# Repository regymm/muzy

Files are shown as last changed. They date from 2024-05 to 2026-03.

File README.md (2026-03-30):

# MUZY

AMD/Xilinx ZYNQ 7010/7020 SoC as generic FPGA development board, no DDR -- cheaper than your Artix 7! 

## MUZY-2

[BGA on 2-layers? It's possible and verified!](muzy2.md)

## MUZY-4

[Now on sale!]()

**Hardware**

- Zynq 7020 (xc7z020-clg400-1)

- RP2040-based JTAG blaster, with DirtyJTAG / XVC Pico firmware, working with OpenFPGALoader and Vivado

- Dual SD Card PS + PL

- Dual Video Out HDMI + VGA 

- Dual USB Host

- Dual PMOD

- 2 switches, 2 buttons, 4 LEDs

- 256 Mb (32 MB) SDRAM

Should be perfect for SoC development & work as a handhold FPGA computer! 

Open-source [Zynq](https://github.com/regymm/GenZ)/[FPGA](https://github.com/OpenXC7) toolchains recommended! 

**JTAG**

There're 3 ways to program the FPGA by JTAG: 

1. Use the standard 2x5 pin header with an external Xilinx dongle.
2. Use the on-board pluggable RP2040 module and [the dirtyJtag firwmare](https://github.com/regymm/pico-dirtyJtag), `./pico_fw/dirtyJtag.uf2`. This supports `openFPGALoader -c dirtyJtag bitstream.bit` style direct programming. Simultaneous UART access also available, usually `/dev/ttyACM0`. Vivado access (and thus ILA) not supported by this firmware. 
3. Use the on-board pluggable RP2040 module and [the xvcPico firmware](https://github.com/regymm/xvc-pico), `./pico_fw/xvcPico.uf2`. Then, launch the daemon in xvcPico (`xvcd-pico`) and 127.0.0.1:2542 for XVC access in Vivado. openFPGALoader can still be used with `openFPGALoader -c xvc-client  --ip 127.1 --port 2542 bitstrea.bit`. Simultaneous UART access also available, usually `/dev/ttyACM0`. 

- For RP Pico firmware update, press the BOOT button down while connecting the USB-C cable, a USB-like device will show up on PC for firmware uploading. 

**Software**

Tested: [Zynq PS No-DDR SD Boot](https://github.com/regymm/GenZ/tree/master/examples/6-noddr-sdboot), [RISC-V SoC Linux booting from SD Card](https://github.com/regymm/quasiSoC/tree/master/rtl/hart_transplant/openla500), Dual video output

**Gallery**

Video: [Linux UART with dual graphics test output](https://www.youtube.com/shorts/H9cZ7YbqNOI)

Pictures: 

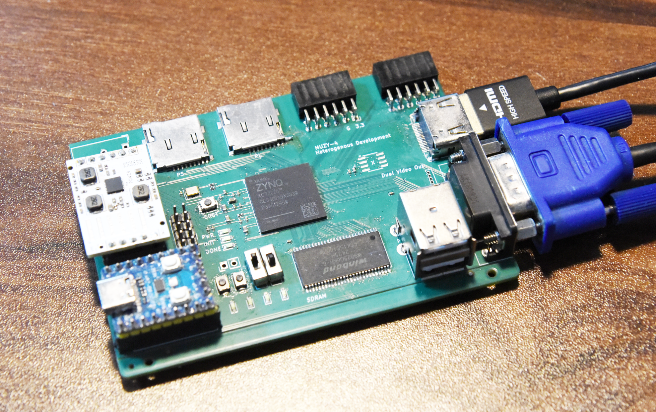
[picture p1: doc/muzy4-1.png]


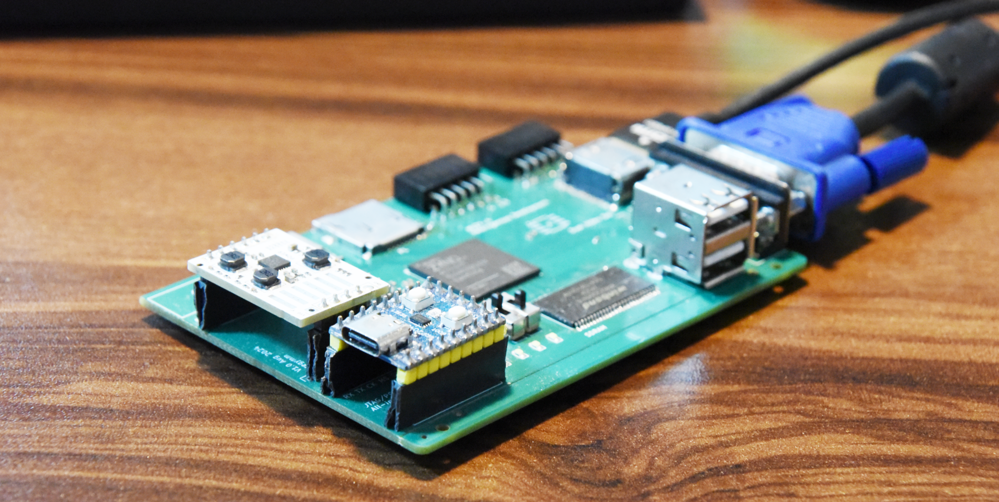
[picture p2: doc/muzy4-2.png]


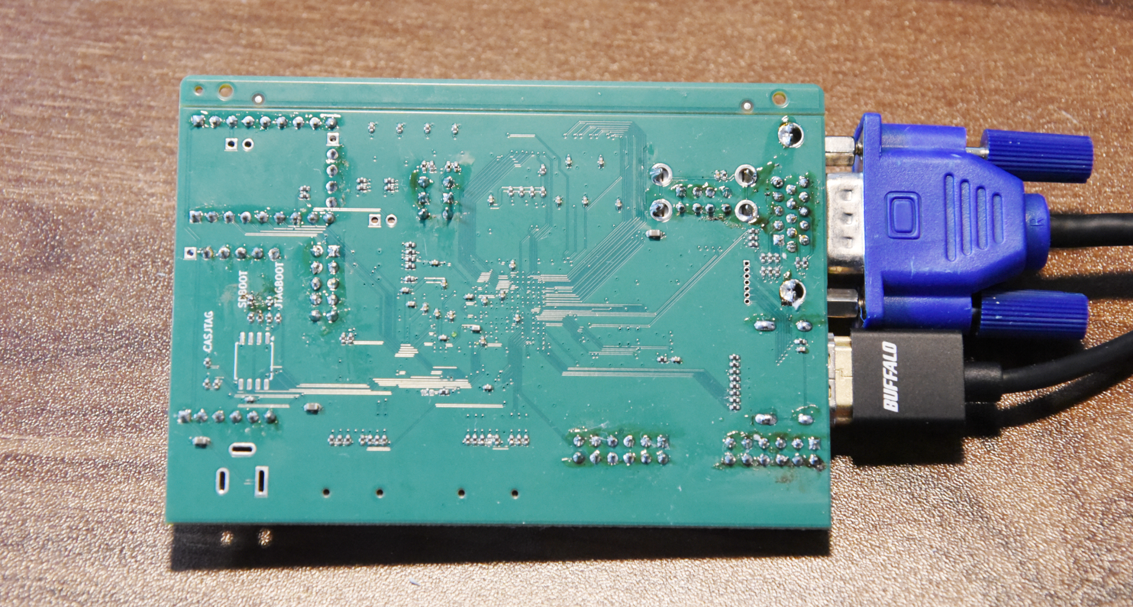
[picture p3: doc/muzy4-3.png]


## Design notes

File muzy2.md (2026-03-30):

# Muzy-2
2-layer FPGA development board with ZYNQ 7010/7020 400-pin BGA.  
Pad size was shrinked due to clearance requirements -- JLCPCB 2-layer 5 mil line width, 0.5/0.3 mm via. 

## Working

PL(FPGA fabric) JTAG & bitstream downloading, SDRAM tested up to 110 MHz, 640x480 VGA, BTN/LED, PMOD

Loading PS(ARM cores) program via JTAG in Xilinx SDK, PS UART, PS SD card, PS EMIO

## Not Working

PL SD card -- due to no pullup resistors! A PMOD SD card module works.

~~PS load bitstream from SD card -- it seems impossible due to no big enough block of memory. Either SPI flash or DDR is required.~~ Now working with GenZ. 

JTAG at 30 MHz maybe not stable. 

## Gallery

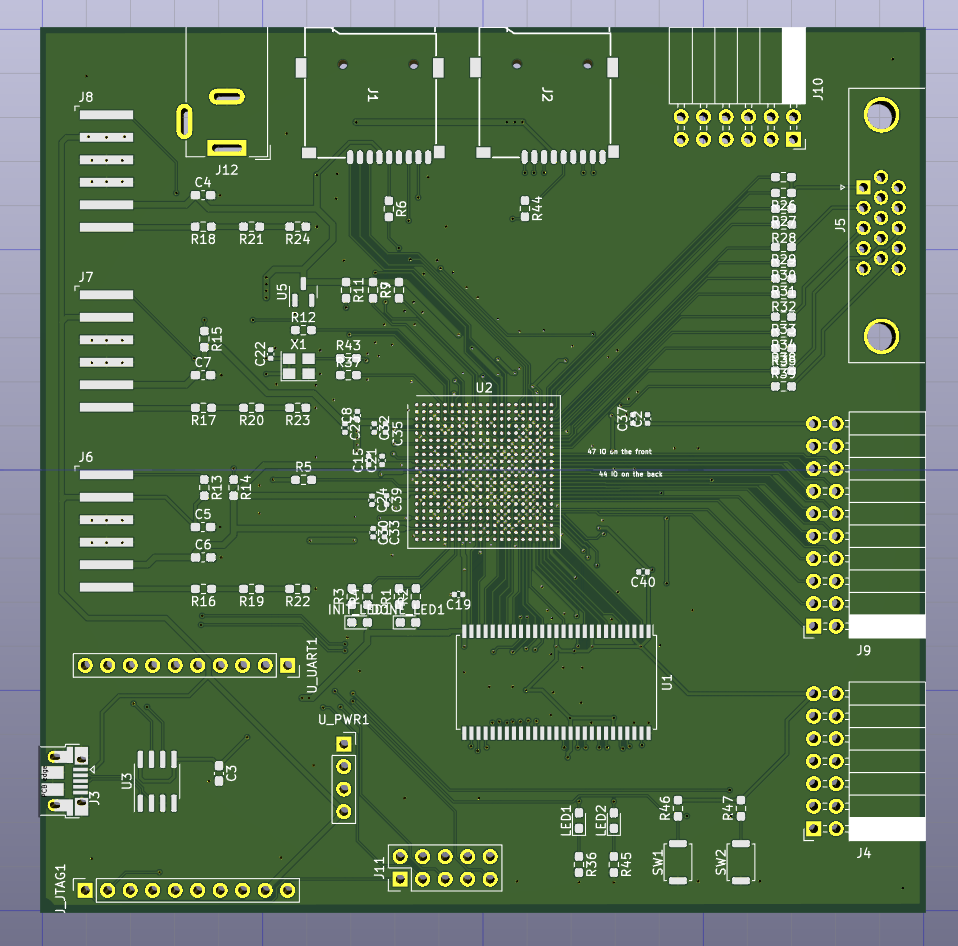
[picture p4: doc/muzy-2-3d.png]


Running with [self-designed JTAG/UART bridge](https://github.com/regymm/ymmcu-ft2232)

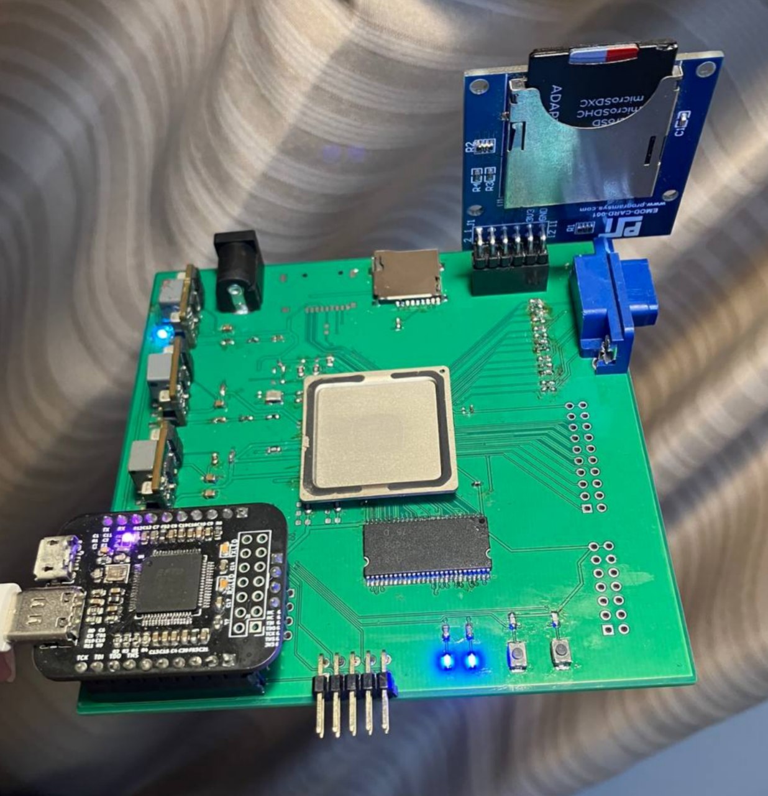
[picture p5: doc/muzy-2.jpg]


Minimum configuration with external power supply and just a few resistors -- back side empty! 



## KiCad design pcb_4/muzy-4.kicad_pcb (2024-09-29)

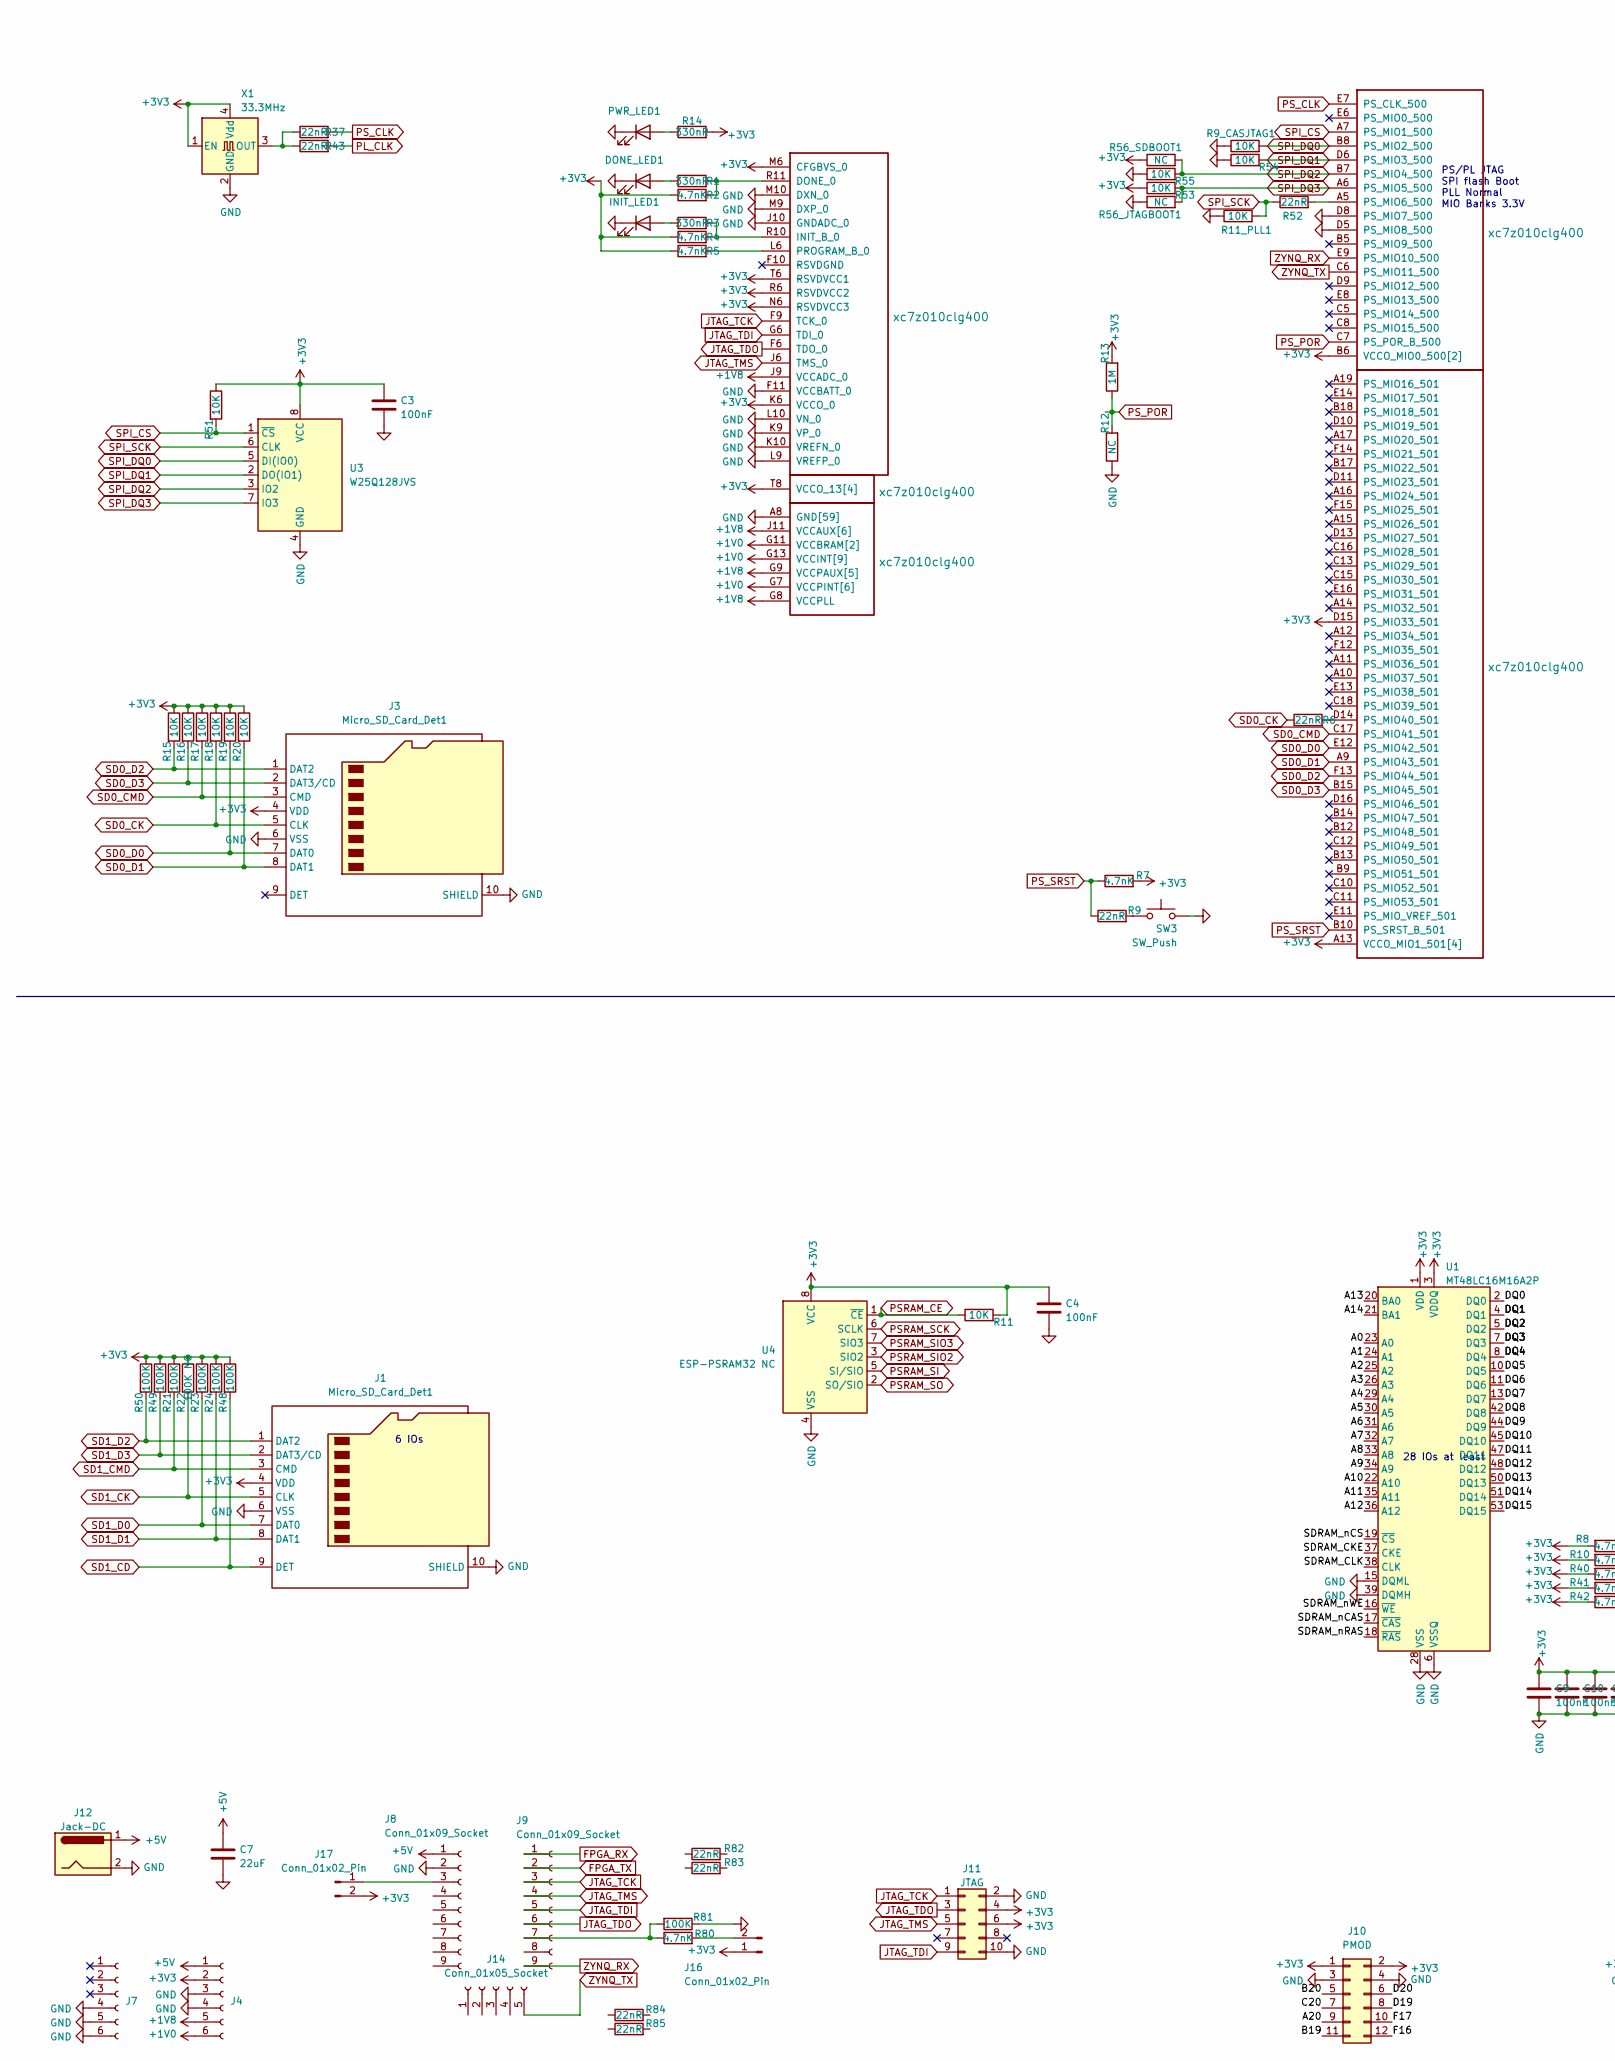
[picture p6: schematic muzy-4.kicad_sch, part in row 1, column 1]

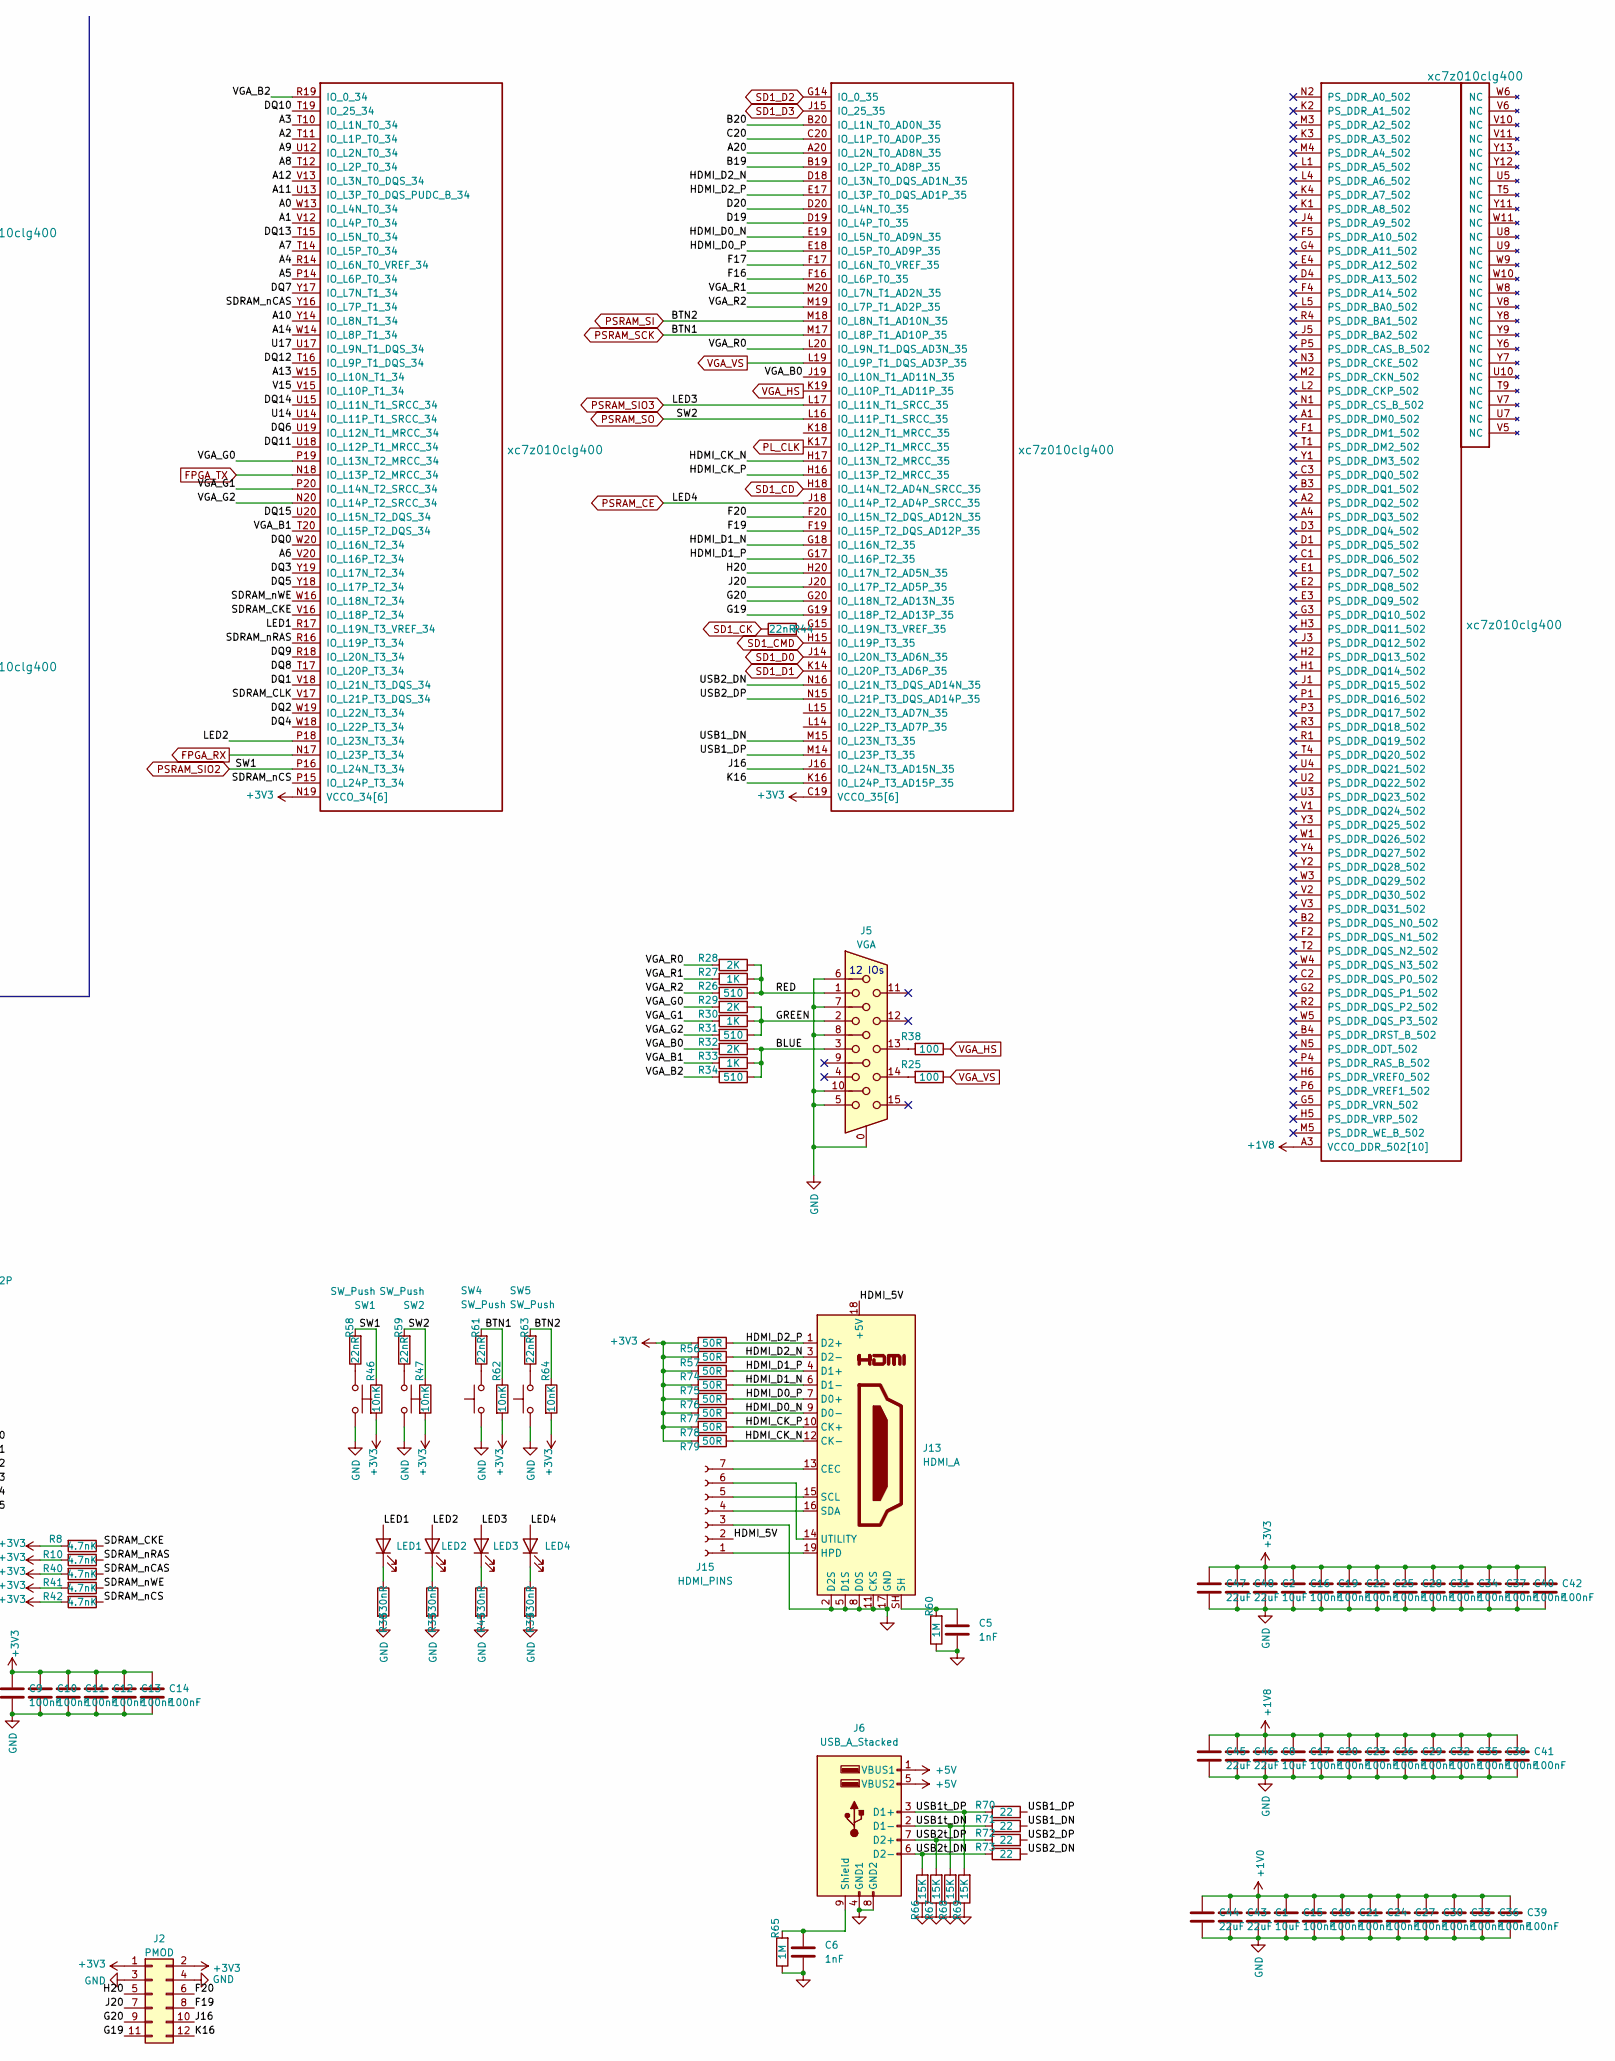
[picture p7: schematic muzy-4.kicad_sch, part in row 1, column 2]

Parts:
C1, C2, C8: 10uF; C_0402_1005Metric
C3, C4, C9, C10, C11, C12, C13, C14, C15, C16, C17, C18, C19, C20, C21, C22, C23, C24, C25, C26, C27, C28, C29, C30, C31, C32, C33, C34, C35, C36, C37, C38, C39, C40, C41, C42: 100nF; C_0402_1005Metric
C5, C6: 1nF; C_0402_1005Metric
C7, C43, C44, C45, C46, C47, C48: 22uF; C_0603_1608Metric
DONE_LED1: LED; LED_0603_1608Metric_Pad1.05x0.95mm_HandSolder
INIT_LED1: LED; LED_0603_1608Metric_Pad1.05x0.95mm_HandSolder
J1, J3: Micro_SD_Card_Det1; SDMICRO_AT
J2, J10: PMOD; PinSocket_2x06_P2.54mm_Horizontal
J4, J7: Conn_01x06_Socket; PinSocket_1x06_P2.54mm_Vertical
J5: VGA; DSUB-15-HD_Female_Horizontal_P2.29x1.98mm_EdgePinOffset3.03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
J6: USB_A_Stacked; USB_A_CUI_UJ2-ADH-TH_Horizontal_Stacked
J8, J9: Conn_01x09_Socket; PinSocket_1x09_P2.54mm_Vertical
J11: JTAG; PinHeader_2x05_P2.54mm_Vertical
J12: Jack-DC; BarrelJack_Wuerth_6941xx301002
J13: HDMI_A; HDMI_A_Molex_208658-1001_Horizontal
J14: Conn_01x05_Socket; PinSocket_1x05_P2.54mm_Vertical
J15: HDMI_PINS; PinSocket_1x07_P1.00mm_Vertical
J16, J17: Conn_01x02_Pin; PinHeader_1x02_P2.54mm_Vertical
LED1, LED2, LED3, LED4: LED; LED_0603_1608Metric_Pad1.05x0.95mm_HandSolder
PWR_LED1: LED; LED_0603_1608Metric_Pad1.05x0.95mm_HandSolder
R1, R3, R14, R35, R36, R39, R45: 330nR; R_0402_1005Metric
R2, R4, R5, R7, R8, R10, R40, R41, R42, R80: 4.7nK; R_0402_1005Metric
R6, R9, R37, R43, R44, R52, R58, R59, R61, R63, R82, R83, R84, R85: 22nR; R_0402_1005Metric
R9_CASJTAG1, R11, R11_PLL1, R15, R16, R17, R18, R19, R20, R51, R53, R54, R55: 10K; R_0402_1005Metric
R12: NC; R_0402_1005Metric_Pad0.72x0.64mm_HandSolder
R13, R65: 1M; R_0402_1005Metric
R21, R23, R24, R48, R49, R50, R81: 100K; R_0402_1005Metric
R22: 100K NC; R_0402_1005Metric
R25, R38: 100; R_0402_1005Metric
R26, R31, R34: 510; R_0402_1005Metric
R27, R30, R33: 1K; R_0402_1005Metric
R28, R29, R32: 2K; R_0402_1005Metric
R46, R47, R62, R64: 10nK; R_0402_1005Metric
R56, R57, R74, R75, R76, R77, R78, R79: 50R; R_0402_1005Metric
R56_JTAGBOOT1, R56_SDBOOT1: NC; R_0402_1005Metric
R60: 1M; R_0402_1005Metric_Pad0.72x0.64mm_HandSolder
R66, R67, R68, R69: 15K; R_0402_1005Metric
R70, R71, R72, R73: 22; R_0402_1005Metric
SW1, SW2: SW_Push; SW_Slide-03_Wuerth-WS-SLTV_10x2.5x6.4_P2.54mm
SW3, SW4, SW5: SW_Push; SW_Push_SPST_NO_Alps_SKRK
U1: MT48LC16M16A2P; TSOP-II-54_22.2x10.16mm_P0.8mm
U2: xc7z010clg400; Xilinx_CLG400_NoPaste_JLC_Package_Delay
U3: W25Q128JVS; SOIC-8_5.23x5.23mm_P1.27mm
U4: ESP-PSRAM32 NC; SOIC-8_3.9x4.9mm_P1.27mm
X1: 33.3MHz; Crystal_SMD_3225-4Pin_3.2x2.5mm

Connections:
+1V0: C1.1, C15.1, C18.1, C21.1, C24.1, C27.1, C30.1, C33.1, C36.1, C39.1, C43.1, C44.1, J4.6, U2.G7 (VCCPINT[6]), U2.G11 (VCCBRAM[2]), U2.G13 (VCCINT[9]), U2.H10 (VCCBRAM[2]), U2.H12 (VCCINT[9]), U2.J7 (VCCPINT[6]), U2.J13 (VCCINT[9]), U2.K12 (VCCINT[9]), U2.L7 (VCCPINT[6]), U2.L13 (VCCINT[9]), U2.M12 (VCCINT[9]), U2.N7 (VCCPINT[6]), U2.N13 (VCCINT[9]), U2.P8 (VCCPINT[6]), U2.P12 (VCCINT[9]), U2.R7 (VCCPINT[6]), U2.R13 (VCCINT[9])
+1V8: C8.1, C17.1, C20.1, C23.1, C26.1, C29.1, C32.1, C35.1, C38.1, C41.1, C45.1, C46.1, J4.5, U2.A3 (VCCO_DDR_502[10]), U2.D2 (VCCO_DDR_502[10]), U2.E5 (VCCO_DDR_502[10]), U2.F8 (VCCPAUX[5]), U2.G1 (VCCO_DDR_502[10]), U2.G8 (VCCPLL), U2.G9 (VCCPAUX[5]), U2.H4 (VCCO_DDR_502[10]), U2.H8 (VCCPAUX[5]), U2.J9 (VCCADC_0), U2.J11 (VCCAUX[6]), U2.K8 (VCCPAUX[5]), U2.L3 (VCCO_DDR_502[10]), U2.L11 (VCCAUX[6]), U2.M8 (VCCPAUX[5]), U2.N9 (VCCAUX[6]), U2.N11 (VCCAUX[6]), U2.P2 (VCCO_DDR_502[10]), U2.P10 (VCCAUX[6]), U2.R5 (VCCO_DDR_502[10]), U2.R9 (VCCAUX[6]), U2.U1 (VCCO_DDR_502[10]), U2.V4 (VCCO_DDR_502[10])
+3V3: C2.1, C3.1, C4.1, C9.1, C10.1, C11.1, C12.1, C13.1, C14.1, C16.1, C19.1, C22.1, C25.1, C28.1, C31.1, C34.1, C37.1, C40.1, C42.1, C47.1, C48.1, J1.4 (VDD), J2.1, J2.2, J3.4 (VDD), J4.2, J10.1, J10.2, J11.4, J11.6, J16.1, J17.2, R2.1, R4.1, R5.1, R7.2, R8.2, R10.2, R11.2, R13.2, R14.2, R15.1, R16.1, R17.1, R18.1, R19.1, R20.1, R21.1, R22.1, R23.1, R24.1, R40.2, R41.2, R42.2, R46.2, R47.2, R48.1, R49.1, R50.1, R51.1, R53.1, R56.2, R56_SDBOOT1.1, R57.2, R62.2, R64.2, R74.2, R75.2, R76.2, R77.2, R78.2, R79.2, U1.1 (VDD), U1.3 (VDDQ), U1.9 (VDDQ), U1.14 (VDD), U1.27 (VDD), U1.43 (VDDQ), U1.49 (VDDQ), U2.A13 (VCCO_MIO1_501[4]), U2.B6 (VCCO_MIO0_500[2]), U2.B16 (VCCO_MIO1_501[4]), U2.C19 (VCCO_35[6]), U2.D7 (VCCO_MIO0_500[2]), U2.D12 (VCCO_MIO1_501[4]), U2.D15 (PS_MIO33_501), U2.E15 (VCCO_MIO1_501[4]), U2.F18 (VCCO_35[6]), U2.H14 (VCCO_35[6]), U2.J17 (VCCO_35[6]), U2.K6 (VCCO_0), U2.K20 (VCCO_35[6]), U2.M6 (CFGBVS_0), U2.M16 (VCCO_35[6]), U2.N6 (RSVDVCC3), U2.N19 (VCCO_34[6]), U2.R6 (RSVDVCC2), U2.R15 (VCCO_34[6]), U2.T6 (RSVDVCC1), U2.T8 (VCCO_13[4]), U2.T18 (VCCO_34[6]), U2.U11 (VCCO_13[4]), U2.V14 (VCCO_34[6]), U2.W7 (VCCO_13[4]), U2.W17 (VCCO_34[6]), U2.Y10 (VCCO_13[4]), U2.Y20 (VCCO_34[6]), U3.8 (VCC), U4.8 (VCC), X1.1 (EN), X1.4 (Vdd)
+5V: C7.1, J4.1, J6.1 (VBUS1), J6.5 (VBUS2), J8.1, J12.1
/A0: U1.23 (A0), U2.W13 (IO_L4N_T0_34)
/A1: U1.24 (A1), U2.V12 (IO_L4P_T0_34)
/A2: U1.25 (A2), U2.T11 (IO_L1P_T0_34)
/A3: U1.26 (A3), U2.T10 (IO_L1N_T0_34)
/A4: U1.29 (A4), U2.R14 (IO_L6N_T0_VREF_34)
/A5: U1.30 (A5), U2.P14 (IO_L6P_T0_34)
/A6: U1.31 (A6), U2.V20 (IO_L16P_T2_34)
/A7: U1.32 (A7), U2.T14 (IO_L5P_T0_34)
/A8: U1.33 (A8), U2.T12 (IO_L2P_T0_34)
/A9: U1.34 (A9), U2.U12 (IO_L2N_T0_34)
/A10: U1.22 (A10), U2.Y14 (IO_L8N_T1_34)
/A11: U1.35 (A11), U2.U13 (IO_L3P_T0_DQS_PUDC_B_34)
/A12: U1.36 (A12), U2.V13 (IO_L3N_T0_DQS_34)
/A13: U1.20 (BA0), U2.W15 (IO_L10N_T1_34)
/A14: U1.21 (BA1), U2.W14 (IO_L8P_T1_34)
/A20: J10.9, U2.A20 (IO_L2N_T0_AD8N_35)
/B19: J10.11, U2.B19 (IO_L2P_T0_AD8P_35)
/B20: J10.5, U2.B20 (IO_L1N_T0_AD0N_35)
/BLUE: J5.3, R32.1, R33.1, R34.1
/C20: J10.7, U2.C20 (IO_L1P_T0_AD0P_35)
/D19: J10.8, U2.D19 (IO_L4P_T0_35)
/D20: J10.6, U2.D20 (IO_L4N_T0_35)
/DQ0: U1.2 (DQ0), U2.W20 (IO_L16N_T2_34)
/DQ1: U1.4 (DQ1), U2.V18 (IO_L21N_T3_DQS_34)
/DQ2: U1.5 (DQ2), U2.W19 (IO_L22N_T3_34)
/DQ3: U1.7 (DQ3), U2.Y19 (IO_L17N_T2_34)
/DQ4: U1.8 (DQ4), U2.W18 (IO_L22P_T3_34)
/DQ5: U1.10 (DQ5), U2.Y18 (IO_L17P_T2_34)
/DQ6: U1.11 (DQ6), U2.U19 (IO_L12N_T1_MRCC_34)
/DQ7: U1.13 (DQ7), U2.Y17 (IO_L7N_T1_34)
/DQ8: U1.42 (DQ8), U2.T17 (IO_L20P_T3_34)
/DQ9: U1.44 (DQ9), U2.R18 (IO_L20N_T3_34)
/DQ10: U1.45 (DQ10), U2.T19 (IO_25_34)
/DQ11: U1.47 (DQ11), U2.U18 (IO_L12P_T1_MRCC_34)
/DQ12: U1.48 (DQ12), U2.T16 (IO_L9P_T1_DQS_34)
/DQ13: U1.50 (DQ13), U2.T15 (IO_L5N_T0_34)
/DQ14: U1.51 (DQ14), U2.U15 (IO_L11N_T1_SRCC_34)
/DQ15: U1.53 (DQ15), U2.U20 (IO_L15N_T2_DQS_34)
/F16: J10.12, U2.F16 (IO_L6P_T0_35)
/F17: J10.10, U2.F17 (IO_L6N_T0_VREF_35)
/F19: J2.8, U2.F19 (IO_L15P_T2_DQS_AD12P_35)
/F20: J2.6, U2.F20 (IO_L15N_T2_DQS_AD12N_35)
/G19: J2.11, U2.G19 (IO_L18P_T2_AD13P_35)
/G20: J2.9, U2.G20 (IO_L18N_T2_AD13N_35)
/GREEN: J5.2, R29.1, R30.1, R31.1
/H20: J2.5, U2.H20 (IO_L17N_T2_AD5N_35)
/HDMI_5V: J13.18 (+5V), J15.2
/HDMI_CK_N: J13.12 (CK-), R79.1, U2.H17 (IO_L13N_T2_MRCC_35)
/HDMI_CK_P: J13.10 (CK+), R78.1, U2.H16 (IO_L13P_T2_MRCC_35)
/HDMI_D0_N: J13.9 (D0-), R77.1, U2.E19 (IO_L5N_T0_AD9N_35)
/HDMI_D0_P: J13.7 (D0+), R76.1, U2.E18 (IO_L5P_T0_AD9P_35)
/HDMI_D1_N: J13.6 (D1-), R75.1, U2.G18 (IO_L16N_T2_35)
/HDMI_D1_P: J13.4 (D1+), R74.1, U2.G17 (IO_L16P_T2_35)
/HDMI_D2_N: J13.3 (D2-), R57.1, U2.D18 (IO_L3N_T0_DQS_AD1N_35)
/HDMI_D2_P: J13.1 (D2+), R56.1, U2.E17 (IO_L3P_T0_DQS_AD1P_35)
/J16: J2.10, U2.J16 (IO_L24N_T3_AD15N_35)
/J20: J2.7, U2.J20 (IO_L17P_T2_AD5P_35)
/K16: J2.12, U2.K16 (IO_L24P_T3_AD15P_35)
/LED1: LED1.2 (A), U2.R17 (IO_L19N_T3_VREF_34)
/LED2: LED2.2 (A), U2.P18 (IO_L23N_T3_34)
/RED: J5.1, R26.1, R27.1, R28.1
/SDRAM_CKE: R8.1, U1.37 (CKE), U2.V16 (IO_L18P_T2_34)
/SDRAM_CLK: U1.38 (CLK), U2.V17 (IO_L21P_T3_DQS_34)
/SDRAM_nCAS: R40.1, U1.17 (~CAS), U2.Y16 (IO_L7P_T1_34)
/SDRAM_nCS: R42.1, U1.19 (~CS), U2.P15 (IO_L24P_T3_34)
/SDRAM_nRAS: R10.1, U1.18 (~RAS), U2.R16 (IO_L19P_T3_34)
/SDRAM_nWE: R41.1, U1.16 (~WE), U2.W16 (IO_L18N_T2_34)
/U14: U2.U14 (IO_L11P_T1_SRCC_34)
/U17: U2.U17 (IO_L9N_T1_DQS_34)
/USB1_DN: R71.2, U2.M15 (IO_L23N_T3_35)
/USB1_DP: R70.2, U2.M14 (IO_L23P_T3_35)
/USB1t_DN: J6.2 (D1-), R68.2, R71.1
/USB1t_DP: J6.3 (D1+), R69.2, R70.1
/USB2_DN: R73.2, U2.N16 (IO_L21N_T3_DQS_AD14N_35)
/USB2_DP: R72.2, U2.N15 (IO_L21P_T3_DQS_AD14P_35)
/USB2t_DN: J6.6 (D2-), R66.2, R73.1
/USB2t_DP: J6.7 (D2+), R67.2, R72.1
/V15: U2.V15 (IO_L10P_T1_34)
/VGA_B0: R32.2, U2.J19 (IO_L10N_T1_AD11N_35)
/VGA_B1: R33.2, U2.T20 (IO_L15P_T2_DQS_34)
/VGA_B2: R34.2, U2.R19 (IO_0_34)
/VGA_G0: R29.2, U2.P19 (IO_L13N_T2_MRCC_34)
/VGA_G1: R30.2, U2.P20 (IO_L14N_T2_SRCC_34)
/VGA_G2: R31.2, U2.N20 (IO_L14P_T2_SRCC_34)
/VGA_R0: R28.2, U2.L20 (IO_L9N_T1_DQS_AD3N_35)
/VGA_R1: R27.2, U2.M20 (IO_L7N_T1_AD2N_35)
/VGA_R2: R26.2, U2.M19 (IO_L7P_T1_AD2P_35)
FPGA_RX: J9.1, U2.N17 (IO_L23P_T3_34)
FPGA_TX: J9.2, U2.N18 (IO_L13P_T2_MRCC_34)
GND: C1.2, C2.2, C3.2, C4.2, C5.2, C6.2, C7.2, C8.2, C9.2, C10.2, C11.2, C12.2, C13.2, C14.2, C15.2, C16.2, C17.2, C18.2, C19.2, C20.2, C21.2, C22.2, C23.2, C24.2, C25.2, C26.2, C27.2, C28.2, C29.2, C30.2, C31.2, C32.2, C33.2, C34.2, C35.2, C36.2, C37.2, C38.2, C39.2, C40.2, C41.2, C42.2, C43.2, C44.2, C45.2, C46.2, C47.2, C48.2, DONE_LED1.1 (K), INIT_LED1.1 (K), J1.6 (VSS), J1.10 (SHIELD), J2.3, J2.4, J3.6 (VSS), J3.10 (SHIELD), J4.3, J4.4, J5.0, J5.5, J5.6, J5.7, J5.8, J5.10, J6.4 (GND1), J6.8 (GND2), J7.4, J7.5, J7.6, J8.2, J10.3, J10.4, J11.2, J11.10, J12.2, J13.2 (D2S), J13.5 (D1S), J13.8 (D0S), J13.11 (CKS), J13.17 (GND), J15.3, PWR_LED1.1 (K), R9_CASJTAG1.1, R11_PLL1.1, R12.1, R35.2, R36.2, R39.2, R45.2, R54.1, R55.1, R56_JTAGBOOT1.1, R60.1, R65.1, R66.1, R67.1, R68.1, R69.1, R81.1, SW1.2, SW2.2, SW3.2, SW4.1, SW5.1, U1.6 (VSSQ), U1.12 (VSSQ), U1.15 (DQML), U1.28 (VSS), U1.39 (DQMH), U1.41 (VSS), U1.46 (VSSQ), U1.52 (VSSQ), U1.54 (VSS), U2.A8 (GND[59]), U2.A18 (GND[59]), U2.B1 (GND[59]), U2.B11 (GND[59]), U2.C4 (GND[59]), U2.C9 (GND[59]), U2.C14 (GND[59]), U2.D5 (PS_MIO8_500), U2.D8 (PS_MIO7_500), U2.D17 (GND[59]), U2.E10 (GND[59]), U2.E20 (GND[59]), U2.F3 (GND[59]), U2.F7 (GND[59]), U2.F11 (VCCBATT_0), U2.G10 (GND[59]), U2.G12 (GND[59]), U2.G16 (GND[59]), U2.H7 (GND[59]), U2.H9 (GND[59]), U2.H11 (GND[59]), U2.H13 (GND[59]), U2.H19 (GND[59]), U2.J2 (GND[59]), U2.J8 (GND[59]), U2.J10 (GNDADC_0), U2.J12 (GND[59]), U2.K5 (GND[59]), U2.K7 (GND[59]), U2.K9 (VP_0), U2.K10 (VREFN_0), U2.K11 (GND[59]), U2.K13 (GND[59]), U2.K15 (GND[59]), U2.L8 (GND[59]), U2.L9 (VREFP_0), U2.L10 (VN_0), U2.L12 (GND[59]), U2.L18 (GND[59]), U2.M1 (GND[59]), U2.M7 (GND[59]), U2.M9 (DXP_0), U2.M10 (DXN_0), U2.M11 (GND[59]), U2.M13 (GND[59]), U2.N4 (GND[59]), U2.N8 (GND[59]), U2.N10 (GND[59]), U2.N12 (GND[59]), U2.N14 (GND[59]), U2.P7 (GND[59]), U2.P9 (GND[59]), U2.P11 (GND[59]), U2.P13 (GND[59]), U2.P17 (GND[59]), U2.R8 (GND[59]), U2.R12 (GND[59]), U2.R20 (GND[59]), U2.T3 (GND[59]), U2.T7 (GND[59]), U2.T13 (GND[59]), U2.U6 (GND[59]), U2.U16 (GND[59]), U2.V9 (GND[59]), U2.V19 (GND[59]), U2.W2 (GND[59]), U2.W12 (GND[59]), U2.Y5 (GND[59]), U2.Y15 (GND[59]), U3.4 (GND), U4.4 (VSS), X1.2 (GND)
JTAG_TCK: J9.3, J11.1, U2.F9 (TCK_0)
JTAG_TDI: J9.5, J11.9, U2.G6 (TDI_0)
JTAG_TDO: J9.6, J11.3, U2.F6 (TDO_0)
JTAG_TMS: J9.4, J11.5, U2.J6 (TMS_0)
unnamed: C5.1, J13.SH, R60.2
unnamed: DONE_LED1.2 (A), R1.1
unnamed: INIT_LED1.2 (A), R3.1
unnamed: J5.13, R38.2
unnamed: J5.14, R25.2
unnamed: C6.1, J6.9 (Shield), R65.2
unnamed: J9.7, R80.1, R81.2
unnamed: J13.13 (CEC), J15.7
unnamed: J13.19 (HPD), J15.1
unnamed: J13.15 (SCL), J15.5
unnamed: J13.16 (SDA), J15.4
unnamed: J13.14 (UTILITY), J15.6
unnamed: J16.2, R80.2
unnamed: J8.3, J17.1
unnamed: LED1.1 (K), R36.1
unnamed: LED2.1 (K), R35.1
unnamed: LED3.1 (K), R45.1
unnamed: LED4.1 (K), R39.1
unnamed: PWR_LED1.2 (A), R14.1
unnamed: R9.2, SW3.1
unnamed: R58.1, SW1.1
unnamed: R59.1, SW2.1
unnamed: R61.1, SW4.2
unnamed: R63.1, SW5.2
unnamed: R1.2, R2.2, U2.R11 (DONE_0)
unnamed: R3.2, R4.2, U2.R10 (INIT_B_0)
unnamed: R5.2, U2.L6 (PROGRAM_B_0)
unnamed: R44.2, U2.G15 (IO_L19N_T3_VREF_35)
unnamed: R52.2, U2.A5 (PS_MIO6_500)
unnamed: R6.2, U2.D14 (PS_MIO40_501)
unnamed: R37.1, R43.1, X1.3 (OUT)
PL_CLK: R43.2, U2.K17 (IO_L12P_T1_MRCC_35)
PSRAM_CE: LED4.2 (A), R11.1, U2.J18 (IO_L14P_T2_AD4P_SRCC_35), U4.1 (~CE)
PSRAM_SCK: R61.2, R62.1, U2.M17 (IO_L8P_T1_AD10P_35), U4.6 (SCLK)
PSRAM_SI: R63.2, R64.1, U2.M18 (IO_L8N_T1_AD10N_35), U4.5 (SI/SIO)
PSRAM_SIO2: R46.1, R58.2, U2.P16 (IO_L24N_T3_34), U4.3 (SIO2)
PSRAM_SIO3: LED3.2 (A), U2.L17 (IO_L11N_T1_SRCC_35), U4.7 (SIO3)
PSRAM_SO: R47.1, R59.2, U2.L16 (IO_L11P_T1_SRCC_35), U4.2 (SO/SIO)
PS_CLK: R37.2, U2.E7 (PS_CLK_500)
PS_POR: R12.2, R13.1, U2.C7 (PS_POR_B_500)
PS_SRST: R7.1, R9.1, U2.B10 (PS_SRST_B_501)
SD0_CK: J3.5 (CLK), R6.1, R18.2
SD0_CMD: J3.3 (CMD), R17.2, U2.C17 (PS_MIO41_501)
SD0_D0: J3.7 (DAT0), R19.2, U2.E12 (PS_MIO42_501)
SD0_D1: J3.8 (DAT1), R20.2, U2.A9 (PS_MIO43_501)
SD0_D2: J3.1 (DAT2), R15.2, U2.F13 (PS_MIO44_501)
SD0_D3: J3.2 (DAT3/CD), R16.2, U2.B15 (PS_MIO45_501)
SD1_CD: J1.9 (DET), R48.2, U2.H18 (IO_L14N_T2_AD4N_SRCC_35)
SD1_CK: J1.5 (CLK), R22.2, R44.1
SD1_CMD: J1.3 (CMD), R21.2, U2.H15 (IO_L19P_T3_35)
SD1_D0: J1.7 (DAT0), R23.2, U2.J14 (IO_L20N_T3_AD6N_35)
SD1_D1: J1.8 (DAT1), R24.2, U2.K14 (IO_L20P_T3_AD6P_35)
SD1_D2: J1.1 (DAT2), R50.2, U2.G14 (IO_0_35)
SD1_D3: J1.2 (DAT3/CD), R49.2, U2.J15 (IO_25_35)
SPI_CS: R51.2, U2.A7 (PS_MIO1_500), U3.1 (~CS)
SPI_DQ0: R9_CASJTAG1.2, U2.B8 (PS_MIO2_500), U3.5 (DI(IO0))
SPI_DQ1: R54.2, U2.D6 (PS_MIO3_500), U3.2 (DO(IO1))
SPI_DQ2: R55.2, R56_SDBOOT1.2, U2.B7 (PS_MIO4_500), U3.3 (IO2)
SPI_DQ3: R53.2, R56_JTAGBOOT1.2, U2.A6 (PS_MIO5_500), U3.7 (IO3)
SPI_SCK: R11_PLL1.2, R52.1, U3.6 (CLK)
VGA_HS: R38.1, U2.K19 (IO_L10P_T1_AD11P_35)
VGA_VS: R25.1, U2.L19 (IO_L9P_T1_DQS_AD3P_35)
ZYNQ_RX: J9.9, U2.E9 (PS_MIO10_500)
ZYNQ_TX: J14.5, U2.C6 (PS_MIO11_500)

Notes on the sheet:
6 IOs
28 IOs at least
PS/PL JTAG SPI flash Boot PLL Normal MIO Banks 3.3V
12 IOs

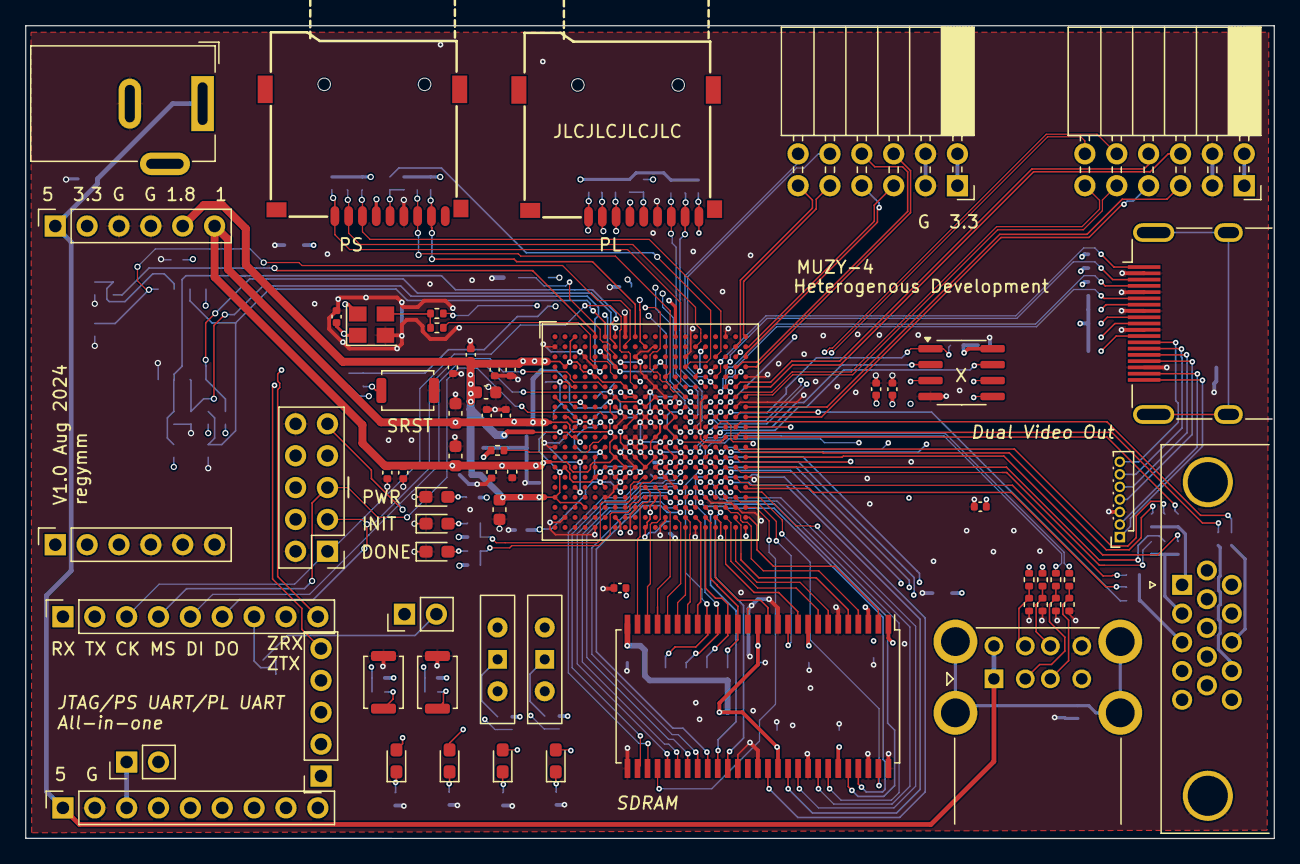
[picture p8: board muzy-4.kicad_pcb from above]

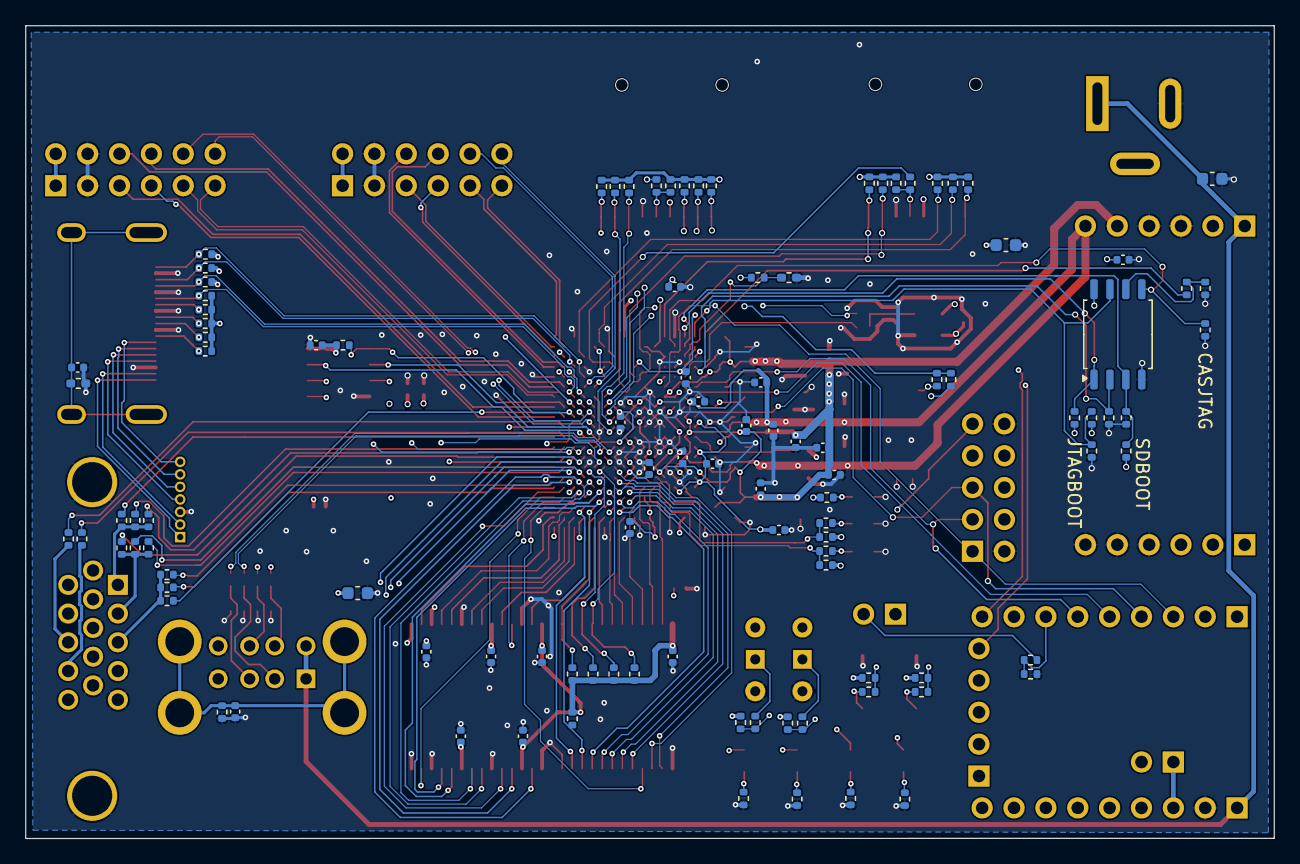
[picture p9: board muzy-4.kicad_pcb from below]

Board: 4 copper layers, 99.5 x 64.8 mm, 167 parts (104 on the bottom side), 159 nets.

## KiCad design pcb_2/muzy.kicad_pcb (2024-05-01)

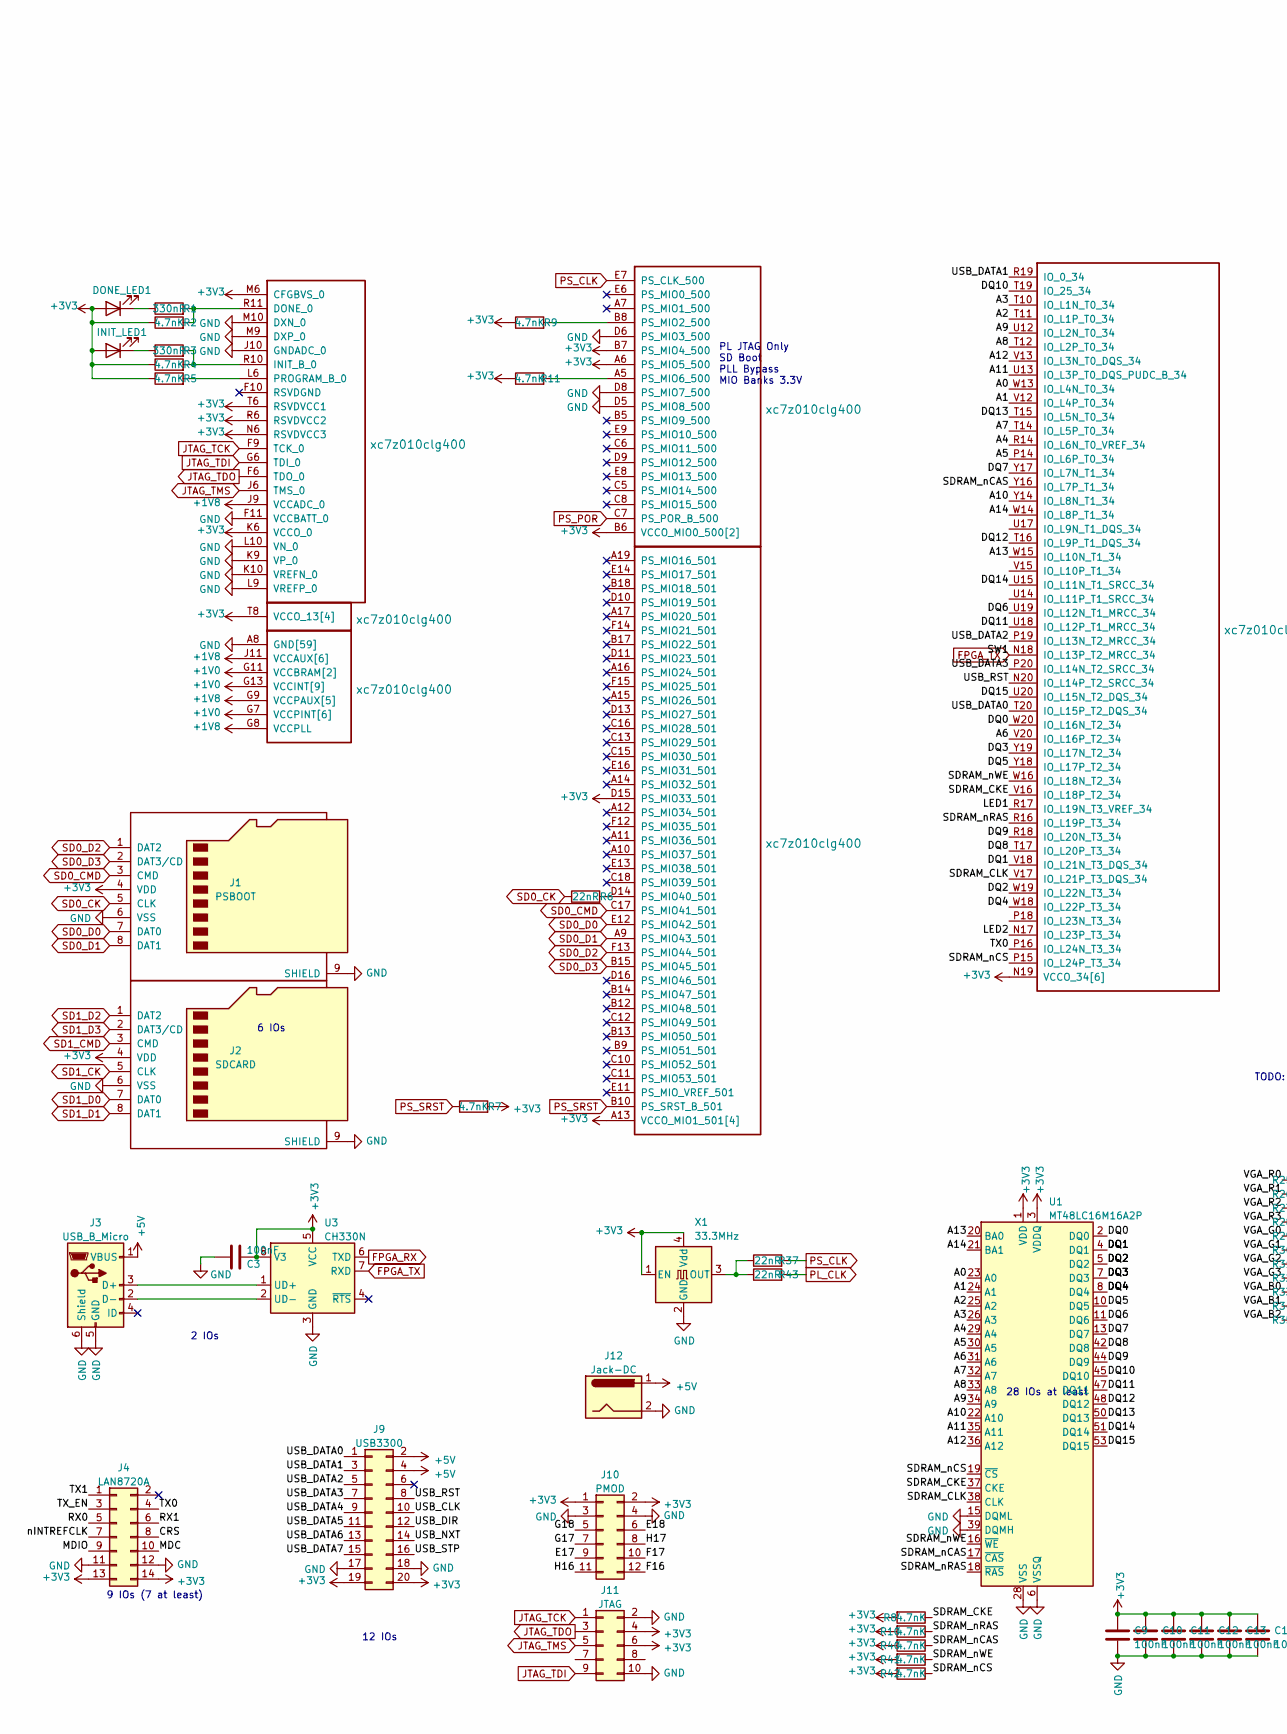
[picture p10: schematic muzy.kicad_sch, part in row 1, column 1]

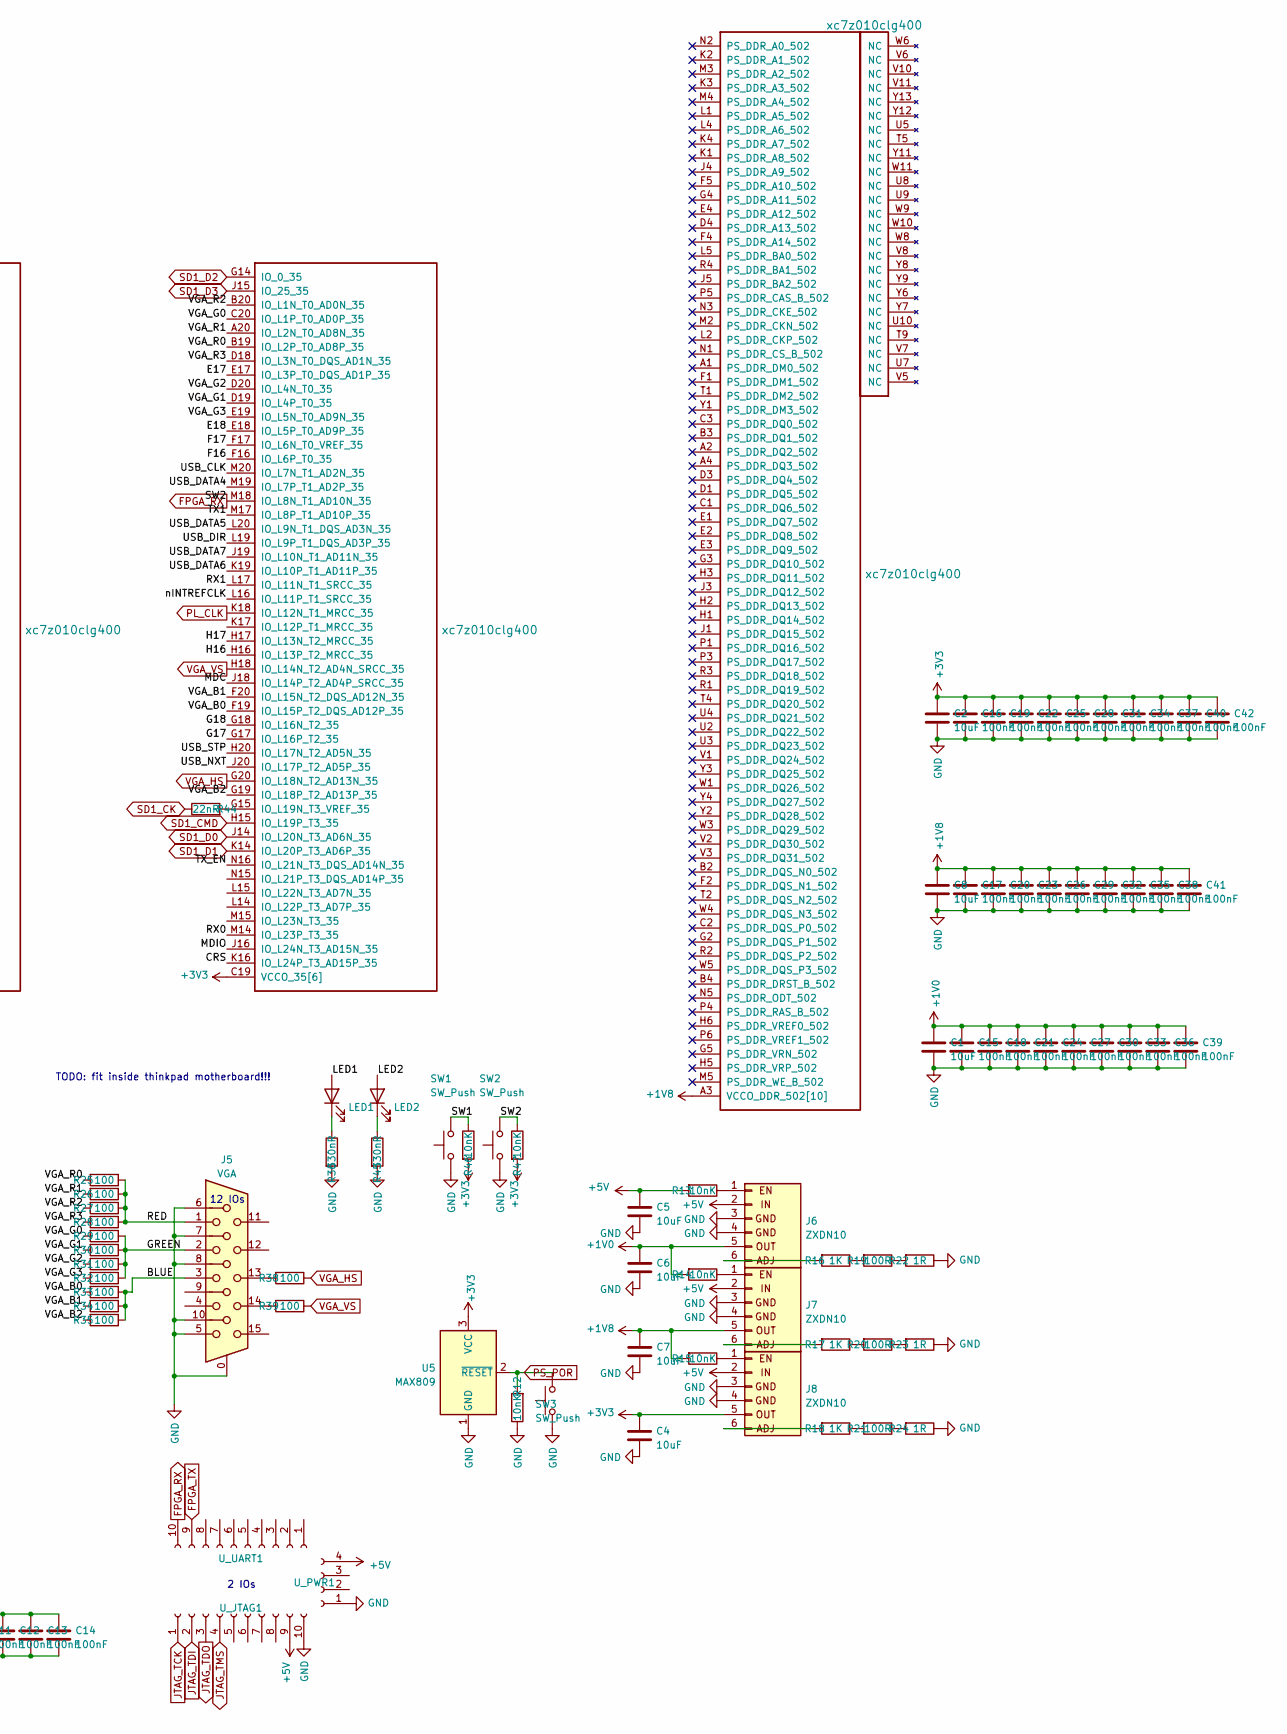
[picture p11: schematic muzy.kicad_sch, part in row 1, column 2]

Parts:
C1, C2, C8: 10uF; C_0402_1005Metric
C3, C9, C10, C11, C12, C13, C14: 100nF; C_0603_1608Metric_Pad1.08x0.95mm_HandSolder
C4, C5, C6, C7: 10uF; C_0603_1608Metric_Pad1.08x0.95mm_HandSolder
C15, C16, C17, C18, C19, C20, C21, C22, C23, C24, C25, C26, C27, C28, C29, C30, C31, C32, C33, C34, C35, C36, C37, C38, C39, C40, C41, C42: 100nF; C_0402_1005Metric
DONE_LED1: LED; LED_0603_1608Metric_Pad1.05x0.95mm_HandSolder
INIT_LED1: LED; LED_0603_1608Metric_Pad1.05x0.95mm_HandSolder
J1: PSBOOT; SDMICRO_AT
J2: SDCARD; SDMICRO_AT
J3: USB_B_Micro; USB_Micro-B_Amphenol_10103594-0001LF_Horizontal
J4: LAN8720A; PinSocket_2x07_P2.54mm_Horizontal
J5: VGA; DSUB-15-HD_Female_Horizontal_P2.29x1.98mm_EdgePinOffset3.03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
J6, J7, J8: ZXDN10; ZX
J9: USB3300; PinSocket_2x10_P2.54mm_Horizontal
J10: PMOD; PinSocket_2x06_P2.54mm_Horizontal
J11: JTAG; PinHeader_2x05_P2.54mm_Vertical
J12: Jack-DC; BarrelJack_Wuerth_6941xx301002
LED1, LED2: LED; LED_0603_1608Metric_Pad1.05x0.95mm_HandSolder
R1, R3, R36, R45: 330nR; R_0603_1608Metric_Pad0.98x0.95mm_HandSolder
R2, R4, R5, R7, R8, R9, R10, R11, R40, R41, R42: 4.7nK; R_0603_1608Metric_Pad0.98x0.95mm_HandSolder
R6, R37, R43, R44: 22nR; R_0603_1608Metric_Pad0.98x0.95mm_HandSolder
R12, R13, R14, R15, R46, R47: 10nK; R_0603_1608Metric_Pad0.98x0.95mm_HandSolder
R16, R17, R18: 1K; R_0603_1608Metric_Pad0.98x0.95mm_HandSolder
R19, R20, R21: 100R; R_0603_1608Metric_Pad0.98x0.95mm_HandSolder
R22, R23, R24: 1R; R_0603_1608Metric_Pad0.98x0.95mm_HandSolder
R25, R26, R27, R28, R29, R30, R31, R32, R33, R34, R35, R38, R39: 100; R_0603_1608Metric_Pad0.98x0.95mm_HandSolder
SW1, SW2, SW3: SW_Push; SW_Push_SPST_NO_Alps_SKRK
U1: MT48LC16M16A2P; TSOP-II-54_22.2x10.16mm_P0.8mm
U2: xc7z010clg400; Xilinx_CLG400_smallpad
U3: CH330N; SOIC-8_3.9x4.9mm_P1.27mm
U5: MAX809; SOT-23
U_JTAG1: Conn_01x10_Female; PinSocket_1x10_P2.54mm_Vertical
U_PWR1: Conn_01x04_Female; PinSocket_1x04_P2.54mm_Vertical
U_UART1: Conn_01x10_Female; PinSocket_1x10_P2.54mm_Vertical
X1: 33.3MHz; Crystal_SMD_3225-4Pin_3.2x2.5mm

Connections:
+1V0: C1.1, C6.1, C15.1, C18.1, C21.1, C24.1, C27.1, C30.1, C33.1, C36.1, C39.1, J6.5 (OUT), R14.2, U2.G7 (VCCPINT[6]), U2.G11 (VCCBRAM[2]), U2.G13 (VCCINT[9]), U2.H10 (VCCBRAM[2]), U2.H12 (VCCINT[9]), U2.J7 (VCCPINT[6]), U2.J13 (VCCINT[9]), U2.K12 (VCCINT[9]), U2.L7 (VCCPINT[6]), U2.L13 (VCCINT[9]), U2.M12 (VCCINT[9]), U2.N7 (VCCPINT[6]), U2.N13 (VCCINT[9]), U2.P8 (VCCPINT[6]), U2.P12 (VCCINT[9]), U2.R7 (VCCPINT[6]), U2.R13 (VCCINT[9])
+1V8: C7.1, C8.1, C17.1, C20.1, C23.1, C26.1, C29.1, C32.1, C35.1, C38.1, C41.1, J7.5 (OUT), R15.2, U2.A3 (VCCO_DDR_502[10]), U2.D2 (VCCO_DDR_502[10]), U2.E5 (VCCO_DDR_502[10]), U2.F8 (VCCPAUX[5]), U2.G1 (VCCO_DDR_502[10]), U2.G8 (VCCPLL), U2.G9 (VCCPAUX[5]), U2.H4 (VCCO_DDR_502[10]), U2.H8 (VCCPAUX[5]), U2.J9 (VCCADC_0), U2.J11 (VCCAUX[6]), U2.K8 (VCCPAUX[5]), U2.L3 (VCCO_DDR_502[10]), U2.L11 (VCCAUX[6]), U2.M8 (VCCPAUX[5]), U2.N9 (VCCAUX[6]), U2.N11 (VCCAUX[6]), U2.P2 (VCCO_DDR_502[10]), U2.P10 (VCCAUX[6]), U2.R5 (VCCO_DDR_502[10]), U2.R9 (VCCAUX[6]), U2.U1 (VCCO_DDR_502[10]), U2.V4 (VCCO_DDR_502[10])
+3V3: C2.1, C3.1, C4.1, C9.1, C10.1, C11.1, C12.1, C13.1, C14.1, C16.1, C19.1, C22.1, C25.1, C28.1, C31.1, C34.1, C37.1, C40.1, C42.1, DONE_LED1.2 (A), INIT_LED1.2 (A), J1.4 (VDD), J2.4 (VDD), J4.13, J4.14, J8.5 (OUT), J9.19, J9.20, J10.1, J10.2, J11.4, J11.6, R2.1, R4.1, R5.1, R7.2, R8.2, R9.1, R10.2, R11.1, R40.2, R41.2, R42.2, R46.2, R47.2, U1.1 (VDD), U1.3 (VDDQ), U1.9 (VDDQ), U1.14 (VDD), U1.27 (VDD), U1.43 (VDDQ), U1.49 (VDDQ), U2.A6 (PS_MIO5_500), U2.A13 (VCCO_MIO1_501[4]), U2.B6 (VCCO_MIO0_500[2]), U2.B7 (PS_MIO4_500), U2.B16 (VCCO_MIO1_501[4]), U2.C19 (VCCO_35[6]), U2.D7 (VCCO_MIO0_500[2]), U2.D12 (VCCO_MIO1_501[4]), U2.D15 (PS_MIO33_501), U2.E15 (VCCO_MIO1_501[4]), U2.F18 (VCCO_35[6]), U2.H14 (VCCO_35[6]), U2.J17 (VCCO_35[6]), U2.K6 (VCCO_0), U2.K20 (VCCO_35[6]), U2.M6 (CFGBVS_0), U2.M16 (VCCO_35[6]), U2.N6 (RSVDVCC3), U2.N19 (VCCO_34[6]), U2.R6 (RSVDVCC2), U2.R15 (VCCO_34[6]), U2.T6 (RSVDVCC1), U2.T8 (VCCO_13[4]), U2.T18 (VCCO_34[6]), U2.U11 (VCCO_13[4]), U2.V14 (VCCO_34[6]), U2.W7 (VCCO_13[4]), U2.W17 (VCCO_34[6]), U2.Y10 (VCCO_13[4]), U2.Y20 (VCCO_34[6]), U3.5 (VCC), U3.8 (V3), U5.3 (VCC), X1.1 (EN), X1.4 (Vdd)
+5V: C5.1, J3.1 (VBUS), J6.2 (IN), J7.2 (IN), J8.2 (IN), J9.2, J9.4, J12.1, R13.2, U_JTAG1.9, U_PWR1.4
/A0: U1.23 (A0), U2.W13 (IO_L4N_T0_34)
/A1: U1.24 (A1), U2.V12 (IO_L4P_T0_34)
/A2: U1.25 (A2), U2.T11 (IO_L1P_T0_34)
/A3: U1.26 (A3), U2.T10 (IO_L1N_T0_34)
/A4: U1.29 (A4), U2.R14 (IO_L6N_T0_VREF_34)
/A5: U1.30 (A5), U2.P14 (IO_L6P_T0_34)
/A6: U1.31 (A6), U2.V20 (IO_L16P_T2_34)
/A7: U1.32 (A7), U2.T14 (IO_L5P_T0_34)
/A8: U1.33 (A8), U2.T12 (IO_L2P_T0_34)
/A9: U1.34 (A9), U2.U12 (IO_L2N_T0_34)
/A10: U1.22 (A10), U2.Y14 (IO_L8N_T1_34)
/A11: U1.35 (A11), U2.U13 (IO_L3P_T0_DQS_PUDC_B_34)
/A12: U1.36 (A12), U2.V13 (IO_L3N_T0_DQS_34)
/A13: U1.20 (BA0), U2.W15 (IO_L10N_T1_34)
/A14: U1.21 (BA1), U2.W14 (IO_L8P_T1_34)
/BLUE: J5.3, R33.1, R34.1, R35.1
/CRS: J4.8, U2.K16 (IO_L24P_T3_AD15P_35)
/DQ0: U1.2 (DQ0), U2.W20 (IO_L16N_T2_34)
/DQ1: U1.4 (DQ1), U2.V18 (IO_L21N_T3_DQS_34)
/DQ2: U1.5 (DQ2), U2.W19 (IO_L22N_T3_34)
/DQ3: U1.7 (DQ3), U2.Y19 (IO_L17N_T2_34)
/DQ4: U1.8 (DQ4), U2.W18 (IO_L22P_T3_34)
/DQ5: U1.10 (DQ5), U2.Y18 (IO_L17P_T2_34)
/DQ6: U1.11 (DQ6), U2.U19 (IO_L12N_T1_MRCC_34)
/DQ7: U1.13 (DQ7), U2.Y17 (IO_L7N_T1_34)
/DQ8: U1.42 (DQ8), U2.T17 (IO_L20P_T3_34)
/DQ9: U1.44 (DQ9), U2.R18 (IO_L20N_T3_34)
/DQ10: U1.45 (DQ10), U2.T19 (IO_25_34)
/DQ11: U1.47 (DQ11), U2.U18 (IO_L12P_T1_MRCC_34)
/DQ12: U1.48 (DQ12), U2.T16 (IO_L9P_T1_DQS_34)
/DQ13: U1.50 (DQ13), U2.T15 (IO_L5N_T0_34)
/DQ14: U1.51 (DQ14), U2.U15 (IO_L11N_T1_SRCC_34)
/DQ15: U1.53 (DQ15), U2.U20 (IO_L15N_T2_DQS_34)
/E17: J10.9, U2.E17 (IO_L3P_T0_DQS_AD1P_35)
/E18: J10.6, U2.E18 (IO_L5P_T0_AD9P_35)
/F16: J10.12, U2.F16 (IO_L6P_T0_35)
/F17: J10.10, U2.F17 (IO_L6N_T0_VREF_35)
/G17: J10.7, U2.G17 (IO_L16P_T2_35)
/G18: J10.5, U2.G18 (IO_L16N_T2_35)
/GREEN: J5.2, R29.1, R30.1, R31.1, R32.1
/H16: J10.11, U2.H16 (IO_L13P_T2_MRCC_35)
/H17: J10.8, U2.H17 (IO_L13N_T2_MRCC_35)
/LED1: LED1.2 (A), U2.R17 (IO_L19N_T3_VREF_34)
/LED2: LED2.2 (A), U2.N17 (IO_L23P_T3_34)
/MDC: J4.10, U2.J18 (IO_L14P_T2_AD4P_SRCC_35)
/MDIO: J4.9, U2.J16 (IO_L24N_T3_AD15N_35)
/RED: J5.1, R25.1, R26.1, R27.1, R28.1
/RX0: J4.5, U2.M14 (IO_L23P_T3_35)
/RX1: J4.6, U2.L17 (IO_L11N_T1_SRCC_35)
/SDRAM_CKE: R8.1, U1.37 (CKE), U2.V16 (IO_L18P_T2_34)
/SDRAM_CLK: U1.38 (CLK), U2.V17 (IO_L21P_T3_DQS_34)
/SDRAM_nCAS: R40.1, U1.17 (~CAS), U2.Y16 (IO_L7P_T1_34)
/SDRAM_nCS: R42.1, U1.19 (~CS), U2.P15 (IO_L24P_T3_34)
/SDRAM_nRAS: R10.1, U1.18 (~RAS), U2.R16 (IO_L19P_T3_34)
/SDRAM_nWE: R41.1, U1.16 (~WE), U2.W16 (IO_L18N_T2_34)
/TX0: J4.4, U2.P16 (IO_L24N_T3_34)
/TX1: J4.1, U2.M17 (IO_L8P_T1_AD10P_35)
/TX_EN: J4.3, U2.N16 (IO_L21N_T3_DQS_AD14N_35)
/USB_CLK: J9.10, U2.M20 (IO_L7N_T1_AD2N_35)
/USB_DATA0: J9.1, U2.T20 (IO_L15P_T2_DQS_34)
/USB_DATA1: J9.3, U2.R19 (IO_0_34)
/USB_DATA2: J9.5, U2.P19 (IO_L13N_T2_MRCC_34)
/USB_DATA3: J9.7, U2.P20 (IO_L14N_T2_SRCC_34)
/USB_DATA4: J9.9, U2.M19 (IO_L7P_T1_AD2P_35)
/USB_DATA5: J9.11, U2.L20 (IO_L9N_T1_DQS_AD3N_35)
/USB_DATA6: J9.13, U2.K19 (IO_L10P_T1_AD11P_35)
/USB_DATA7: J9.15, U2.J19 (IO_L10N_T1_AD11N_35)
/USB_DIR: J9.12, U2.L19 (IO_L9P_T1_DQS_AD3P_35)
/USB_NXT: J9.14, U2.J20 (IO_L17P_T2_AD5P_35)
/USB_RST: J9.8, U2.N20 (IO_L14P_T2_SRCC_34)
/USB_STP: J9.16, U2.H20 (IO_L17N_T2_AD5N_35)
/VGA_B0: R33.2, U2.F19 (IO_L15P_T2_DQS_AD12P_35)
/VGA_B1: R34.2, U2.F20 (IO_L15N_T2_DQS_AD12N_35)
/VGA_B2: R35.2, U2.G19 (IO_L18P_T2_AD13P_35)
/VGA_G0: R29.2, U2.C20 (IO_L1P_T0_AD0P_35)
/VGA_G1: R30.2, U2.D19 (IO_L4P_T0_35)
/VGA_G2: R31.2, U2.D20 (IO_L4N_T0_35)
/VGA_G3: R32.2, U2.E19 (IO_L5N_T0_AD9N_35)
/VGA_R0: R25.2, U2.B19 (IO_L2P_T0_AD8P_35)
/VGA_R1: R26.2, U2.A20 (IO_L2N_T0_AD8N_35)
/VGA_R2: R27.2, U2.B20 (IO_L1N_T0_AD0N_35)
/VGA_R3: R28.2, U2.D18 (IO_L3N_T0_DQS_AD1N_35)
/nINTREFCLK: J4.7, U2.L16 (IO_L11P_T1_SRCC_35)
FPGA_RX: R47.1, SW2.2, U2.M18 (IO_L8N_T1_AD10N_35), U3.6 (TXD), U_UART1.10
FPGA_TX: R46.1, SW1.2, U2.N18 (IO_L13P_T2_MRCC_34), U3.7 (RXD), U_UART1.9
GND: C1.2, C2.2, C3.2, C4.2, C5.2, C6.2, C7.2, C8.2, C9.2, C10.2, C11.2, C12.2, C13.2, C14.2, C15.2, C16.2, C17.2, C18.2, C19.2, C20.2, C21.2, C22.2, C23.2, C24.2, C25.2, C26.2, C27.2, C28.2, C29.2, C30.2, C31.2, C32.2, C33.2, C34.2, C35.2, C36.2, C37.2, C38.2, C39.2, C40.2, C41.2, C42.2, J1.6 (VSS), J1.9 (SHIELD), J2.6 (VSS), J2.9 (SHIELD), J3.5 (GND), J3.6 (Shield), J4.11, J4.12, J5.0, J5.5, J5.6, J5.7, J5.8, J5.10, J6.3 (GND), J6.4 (GND), J7.3 (GND), J7.4 (GND), J8.3 (GND), J8.4 (GND), J9.17, J9.18, J10.3, J10.4, J11.2, J11.10, J12.2, R12.1, R22.1, R23.1, R24.1, R36.2, R45.2, SW1.1, SW2.1, SW3.1, U1.6 (VSSQ), U1.12 (VSSQ), U1.15 (DQML), U1.28 (VSS), U1.39 (DQMH), U1.41 (VSS), U1.46 (VSSQ), U1.52 (VSSQ), U1.54 (VSS), U2.A8 (GND[59]), U2.A18 (GND[59]), U2.B1 (GND[59]), U2.B11 (GND[59]), U2.C4 (GND[59]), U2.C9 (GND[59]), U2.C14 (GND[59]), U2.D5 (PS_MIO8_500), U2.D6 (PS_MIO3_500), U2.D8 (PS_MIO7_500), U2.D17 (GND[59]), U2.E10 (GND[59]), U2.E20 (GND[59]), U2.F3 (GND[59]), U2.F7 (GND[59]), U2.F11 (VCCBATT_0), U2.G10 (GND[59]), U2.G12 (GND[59]), U2.G16 (GND[59]), U2.H7 (GND[59]), U2.H9 (GND[59]), U2.H11 (GND[59]), U2.H13 (GND[59]), U2.H19 (GND[59]), U2.J2 (GND[59]), U2.J8 (GND[59]), U2.J10 (GNDADC_0), U2.J12 (GND[59]), U2.K5 (GND[59]), U2.K7 (GND[59]), U2.K9 (VP_0), U2.K10 (VREFN_0), U2.K11 (GND[59]), U2.K13 (GND[59]), U2.K15 (GND[59]), U2.L8 (GND[59]), U2.L9 (VREFP_0), U2.L10 (VN_0), U2.L12 (GND[59]), U2.L18 (GND[59]), U2.M1 (GND[59]), U2.M7 (GND[59]), U2.M9 (DXP_0), U2.M10 (DXN_0), U2.M11 (GND[59]), U2.M13 (GND[59]), U2.N4 (GND[59]), U2.N8 (GND[59]), U2.N10 (GND[59]), U2.N12 (GND[59]), U2.N14 (GND[59]), U2.P7 (GND[59]), U2.P9 (GND[59]), U2.P11 (GND[59]), U2.P13 (GND[59]), U2.P17 (GND[59]), U2.R8 (GND[59]), U2.R12 (GND[59]), U2.R20 (GND[59]), U2.T3 (GND[59]), U2.T7 (GND[59]), U2.T13 (GND[59]), U2.U6 (GND[59]), U2.U16 (GND[59]), U2.V9 (GND[59]), U2.V19 (GND[59]), U2.W2 (GND[59]), U2.W12 (GND[59]), U2.Y5 (GND[59]), U2.Y15 (GND[59]), U3.3 (GND), U5.1 (GND), U_JTAG1.10, U_PWR1.1, X1.2 (GND)
JTAG_TCK: J11.1, U2.F9 (TCK_0), U_JTAG1.1
JTAG_TDI: J11.9, U2.G6 (TDI_0), U_JTAG1.2
JTAG_TDO: J11.3, U2.F6 (TDO_0), U_JTAG1.3
JTAG_TMS: J11.5, U2.J6 (TMS_0), U_JTAG1.4
unnamed: DONE_LED1.1 (K), R1.1
unnamed: INIT_LED1.1 (K), R3.1
unnamed: J3.2 (D-), U3.2 (UD-)
unnamed: J3.3 (D+), U3.1 (UD+)
unnamed: J5.13, R38.2
unnamed: J5.14, R39.2
unnamed: J6.1 (EN), R13.1
unnamed: J6.6 (ADJ), R16.2
unnamed: J7.1 (EN), R14.1
unnamed: J7.6 (ADJ), R17.2
unnamed: J8.1 (EN), R15.1
unnamed: J8.6 (ADJ), R18.2
unnamed: LED1.1 (K), R36.1
unnamed: LED2.1 (K), R45.1
unnamed: R1.2, R2.2, U2.R11 (DONE_0)
unnamed: R3.2, R4.2, U2.R10 (INIT_B_0)
unnamed: R5.2, U2.L6 (PROGRAM_B_0)
unnamed: R6.2, U2.D14 (PS_MIO40_501)
unnamed: R9.2, U2.B8 (PS_MIO2_500)
unnamed: R11.2, U2.A5 (PS_MIO6_500)
unnamed: R16.1, R19.2
unnamed: R17.1, R20.2
unnamed: R18.1, R21.2
unnamed: R19.1, R22.2
unnamed: R20.1, R23.2
unnamed: R21.1, R24.2
unnamed: R37.1, R43.1, X1.3 (OUT)
unnamed: R44.2, U2.G15 (IO_L19N_T3_VREF_35)
PL_CLK: R43.2, U2.K18 (IO_L12N_T1_MRCC_35)
PS_CLK: R37.2, U2.E7 (PS_CLK_500)
PS_POR: R12.2, SW3.2, U2.C7 (PS_POR_B_500), U5.2 (~RESET)
PS_SRST: R7.1, U2.B10 (PS_SRST_B_501)
SD0_CK: J1.5 (CLK), R6.1
SD0_CMD: J1.3 (CMD), U2.C17 (PS_MIO41_501)
SD0_D0: J1.7 (DAT0), U2.E12 (PS_MIO42_501)
SD0_D1: J1.8 (DAT1), U2.A9 (PS_MIO43_501)
SD0_D2: J1.1 (DAT2), U2.F13 (PS_MIO44_501)
SD0_D3: J1.2 (DAT3/CD), U2.B15 (PS_MIO45_501)
SD1_CK: J2.5 (CLK), R44.1
SD1_CMD: J2.3 (CMD), U2.H15 (IO_L19P_T3_35)
SD1_D0: J2.7 (DAT0), U2.J14 (IO_L20N_T3_AD6N_35)
SD1_D1: J2.8 (DAT1), U2.K14 (IO_L20P_T3_AD6P_35)
SD1_D2: J2.1 (DAT2), U2.G14 (IO_0_35)
SD1_D3: J2.2 (DAT3/CD), U2.J15 (IO_25_35)
VGA_HS: R38.1, U2.G20 (IO_L18N_T2_AD13N_35)
VGA_VS: R39.1, U2.H18 (IO_L14N_T2_AD4N_SRCC_35)

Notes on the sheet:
12 IOs
6 IOs
28 IOs at least
2 IOs
9 IOs (7 at least)
PL JTAG Only SD Boot PLL Bypass MIO Banks 3.3V
TODO: fit inside thinkpad motherboard!!!

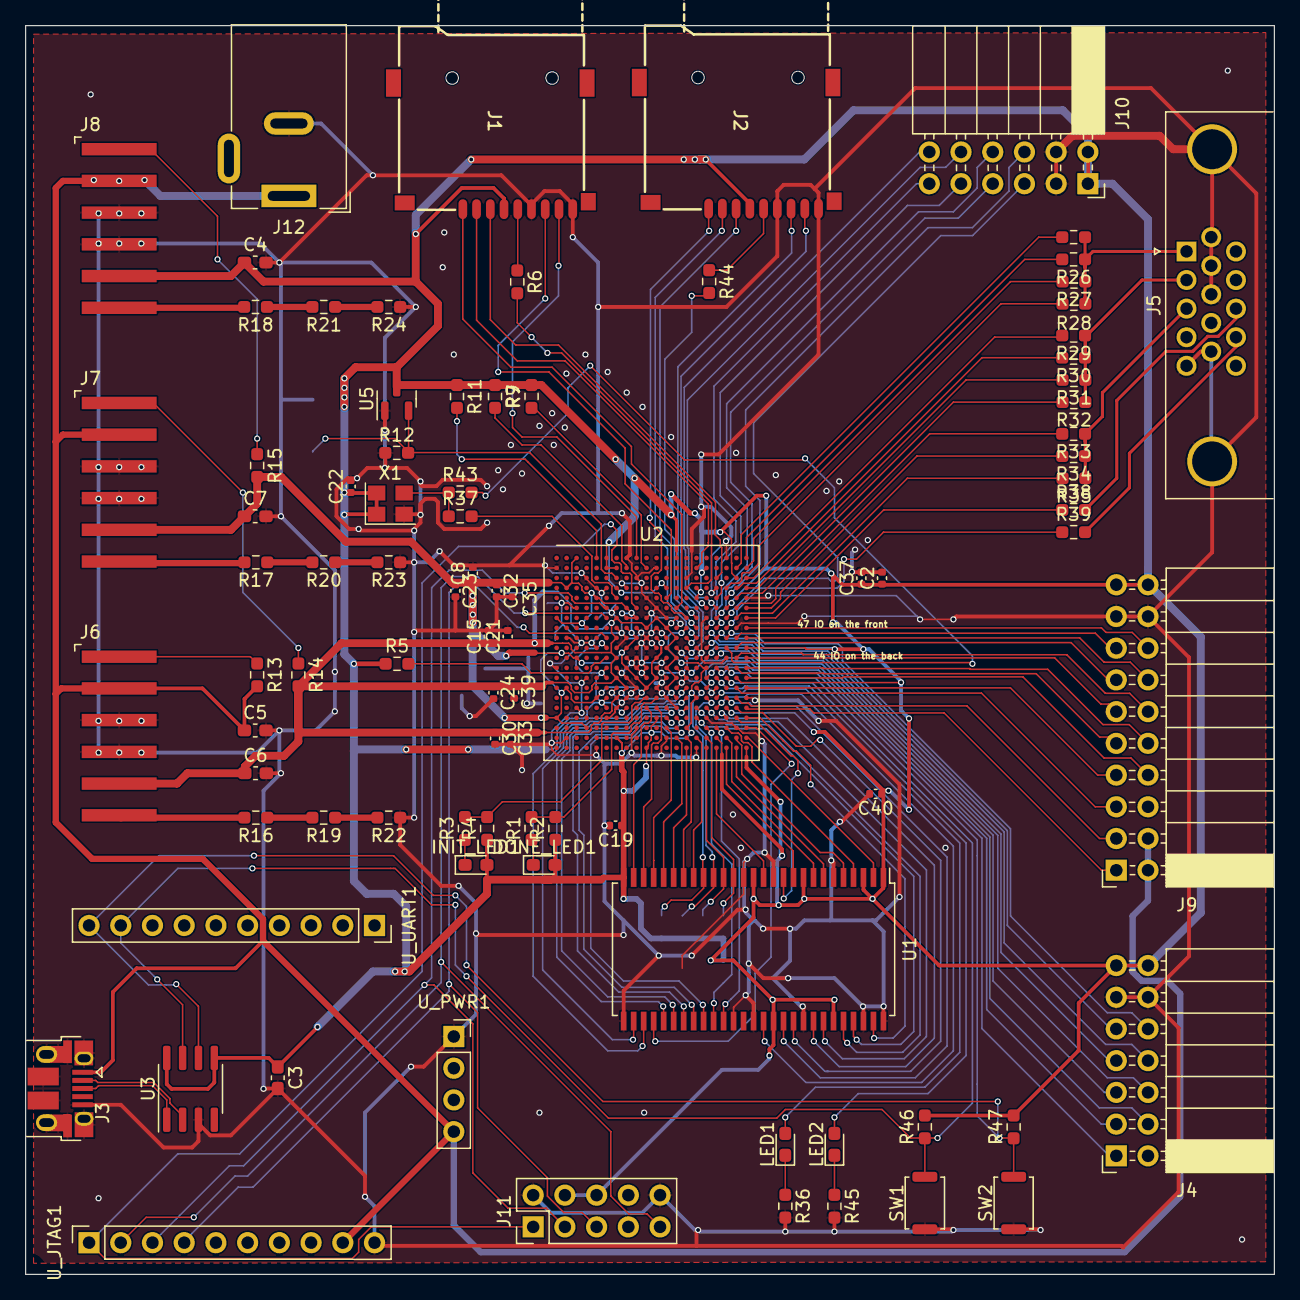
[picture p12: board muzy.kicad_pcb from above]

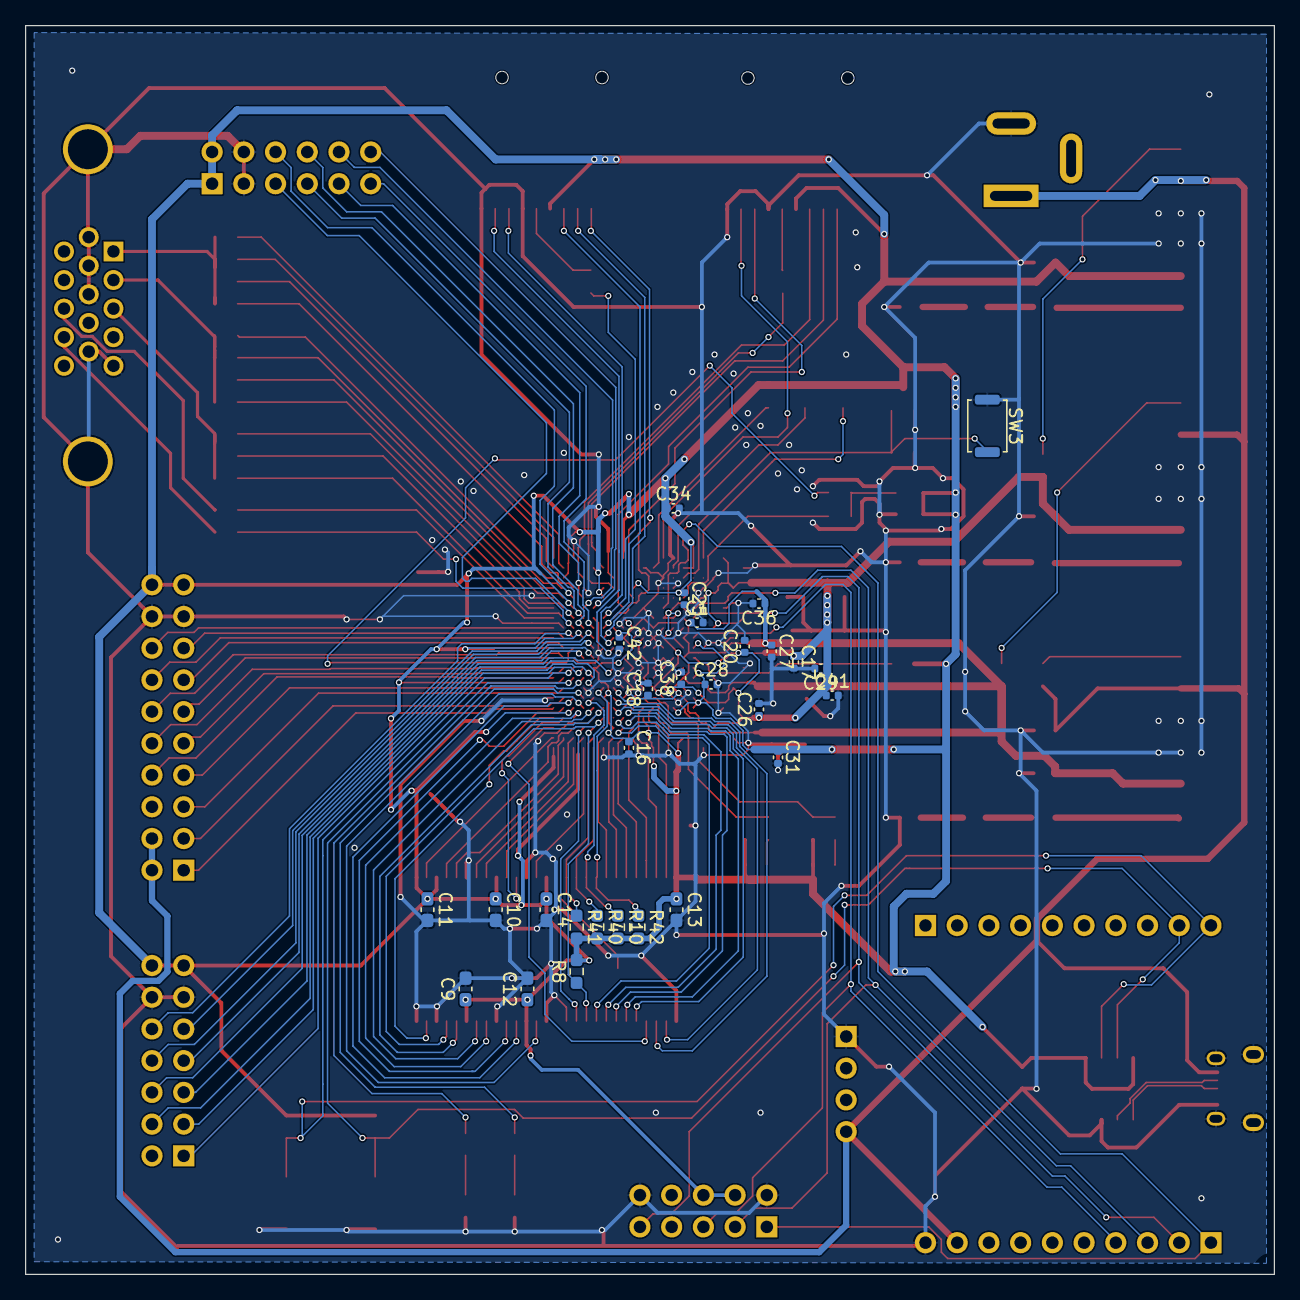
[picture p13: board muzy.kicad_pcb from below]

Board: 2 copper layers, 100.0 x 100.0 mm, 116 parts (28 on the bottom side), 140 nets.

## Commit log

2024-05-01 Added files and README
    [muzy.kicad_pcb, muzy.kicad_sch]
2024-09-29 added muzy 4
    [muzy-4.kicad_pcb, muzy-4.kicad_sch, muzy.kicad_pcb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]
2026-03-30 Updated pico firmware usage
